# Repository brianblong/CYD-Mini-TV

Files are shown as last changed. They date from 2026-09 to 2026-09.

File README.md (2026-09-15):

# Mini TV

A DIY Wi-Fi picture frame built around an **ESP32-2432S028** display. The
project combines ESP32 firmware, a self-hosted photo portal, and a printable
retro television enclosure.

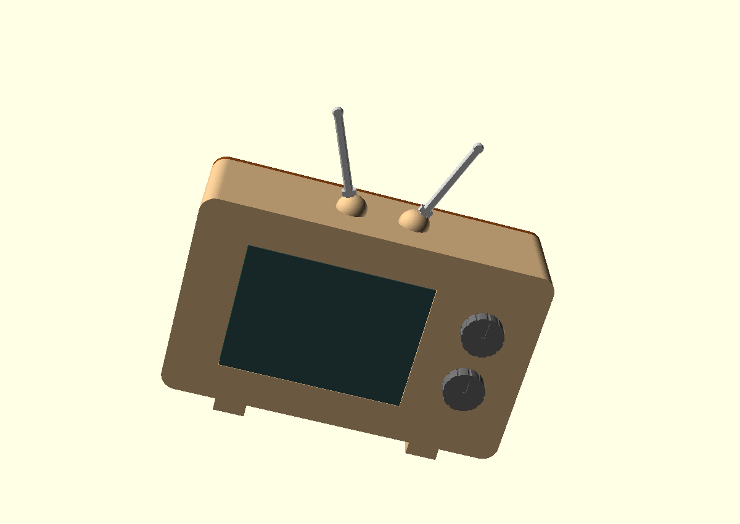
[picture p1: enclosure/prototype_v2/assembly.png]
Assembled retro Mini TV enclosure


The finished device can:

- display an ordered slideshow supplied by your own private server
- keep displaying a saved frame when the network is temporarily unavailable
- report device status to the photo portal
- receive signed firmware updates
- let you upload, arrange, preview, and remove pictures in a browser
- fit inside the included 3D-printable retro TV enclosure

This repository is a reusable blank template. It contains no personal photos,
Wi-Fi credentials, passwords, private signing keys, or deployment-specific
network details.

## How the pieces work together

```mermaid
flowchart LR
    A[Web browser] -->|HTTPS /admin| B[Reverse proxy]
    T[Mini TV] -->|HTTPS + device login| B
    B -->|Private container network| P[Flask photo portal]
    P --> D[(Photo catalogue)]
    P --> F[(Private firmware releases)]
    P -->|320 x 240 RGB565 frame| B
    B -->|Next slideshow frame| T
```

The browser is the control panel. The Mini TV is a separate authenticated
client. NGINX (or an equivalent reverse proxy) terminates HTTPS, verifies the
device login, and forwards trusted requests to the private Flask application.
The Flask application should not be exposed directly to the internet.

## Choose your starting point

| Goal | What you need | Start here |
| --- | --- | --- |
| See the portal without hardware | Python 3 and a browser | [Preview the portal](#1-preview-the-photo-portal) |
| Test the display | ESP32-2432S028, USB data cable, VS Code, PlatformIO | [Test the screen](#2-build-and-test-the-display) |
| Build the enclosure | 3D printer or printing service | [Print the enclosure](#3-print-the-enclosure) |
| Run the complete picture frame | All of the above plus a server, domain name, and HTTPS | [Deploy the complete system](#4-deploy-the-complete-system) |

## What you need

### Hardware

- one ESP32-2432S028 display board, often called a Cheap Yellow Display (CYD)
- a data-capable USB cable that fits your board revision
- a stable USB power supply for normal operation
- a microSD card only if you extend the project to use one; it is not required
  by the included network slideshow
- the printed enclosure parts and fasteners described below

ESP32-2432S028 boards are sold with different display controllers and connector
layouts. This repository includes ST7789 and ILI9341 build profiles, but you must
verify your own board. The manufacturer's
[reference downloads](https://www.guition.com/-download) are useful background;
physical measurements and a display test take priority.

### Software

- [Visual Studio Code](https://code.visualstudio.com/)
- the [PlatformIO IDE extension](https://platformio.org/install/ide?install=vscode)
- [Python 3](https://www.python.org/downloads/)
- Git, if you want to clone the repository
- Docker and a reverse proxy for a permanent server deployment
- OpenSCAD and a slicer such as Bambu Studio only if you want to modify or print
  the enclosure

## Project layout

```text
mini-tv/
|-- firmware/             ESP32 source, local settings template, and OTA tools
|-- homelab/portal/       Flask portal, browser interface, tests, and NGINX config
|-- enclosure/            OpenSCAD sources, STL files, renders, and print notes
|-- .gitignore            Prevents private/generated files from entering Git
|-- LICENSE               MIT license
`-- README.md             This guide
```

## 1. Preview the photo portal

Do this first if you want to explore the interface without configuring a server
or connecting the display. The preview listens only on your own computer and
creates temporary sample images.

1. Clone the repository and enter its directory:

   ```powershell
   git clone https://github.com/brianblong/CYD-Mini-TV.git
   cd CYD-Mini-TV
   ```

2. Create a private Python environment:

   ```powershell
   python -m venv .venv
   ```

3. Activate it in PowerShell:

   ```powershell
   .\.venv\Scripts\Activate.ps1
   ```

   If PowerShell blocks activation, use the environment's Python directly:

   ```powershell
   .\.venv\Scripts\python.exe -m pip install -r homelab\portal\requirements.txt
   .\.venv\Scripts\python.exe homelab\portal\preview.py
   ```

4. If activation succeeded, install the dependencies and start the preview:

   ```powershell
   python -m pip install -r homelab\portal\requirements.txt
   python homelab\portal\preview.py
   ```

5. Open <http://127.0.0.1:8765/admin/> in your browser.

6. When finished, return to the terminal and press **Ctrl+C** to stop it.

The preview is for inspecting the design. For persistent photos and an actual
Mini TV connection, continue to the deployment section.

## 2. Build and test the display

Start with the safe blank configuration. This verifies the display controller,
orientation, colors, USB connection, and build tools before credentials are added.

1. Install VS Code and the PlatformIO IDE extension.
2. In VS Code, choose **File > Open Folder** and open the repository's
   `firmware` folder—not the repository root.
3. Connect the ESP32 display with a data-capable USB cable. A charge-only cable
   can power the board but cannot upload firmware.
4. Wait for PlatformIO to finish installing the pinned ESP32 platform and
   libraries on its first run.
5. In the PlatformIO sidebar, open
   **Project Tasks > cyd_st7789_check > General > Build**.
6. A successful build ends with `SUCCESS`. This check uses the public blank
   settings and is safe to compile, but is not intended for normal network use.
7. To test the common ST7789 board, select
   **Project Tasks > cyd_st7789 > General > Upload**. With blank settings, the
   screen shows the neutral startup/color test instead of connecting to Wi-Fi.
8. If the image has the wrong colors, orientation, or no usable output, try the
   **cyd_ili9341** environment.
9. Open **Monitor** under the same environment to view diagnostic messages. The
   serial speed is **115200 baud**.
10. If PlatformIO cannot choose a port, find the board's COM port in Windows
    Device Manager and temporarily add these lines under `[env]` in
    `firmware/platformio.ini`:

    ```ini
    upload_port = COM3
    monitor_port = COM3
    ```

    Replace `COM3` with the port shown on your computer. Avoid committing a
    machine-specific port unless you intentionally want it in your fork.

For controller details, see the [firmware guide](firmware/README.md).

## 3. Print the enclosure

The recommended enclosure is **Prototype V3**, which has threads built into its
PCB supports and rear posts. It reuses the V2 exterior geometry and no longer
requires eight separate nuts.

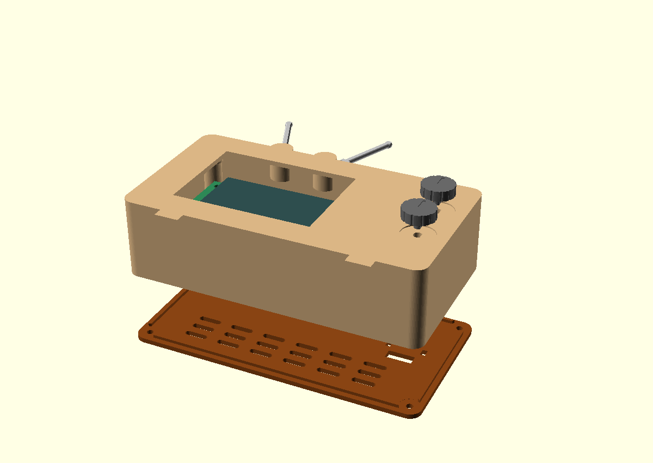
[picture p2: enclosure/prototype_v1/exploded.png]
Exploded enclosure showing the screen, housing, controls, and back


### Parts to print

From `enclosure/prototype_v3/`:

- `housing.stl` — main television body
- `back_cover.stl` — removable ventilated rear cover
- `knobs.stl` — decorative front controls
- `antennas.stl` — decorative top antennas

Before printing the full housing, also print:

- `fit_coupon.stl` — small threaded test section
- `test_spacers.stl` — simulates the PCB and back-cover thicknesses

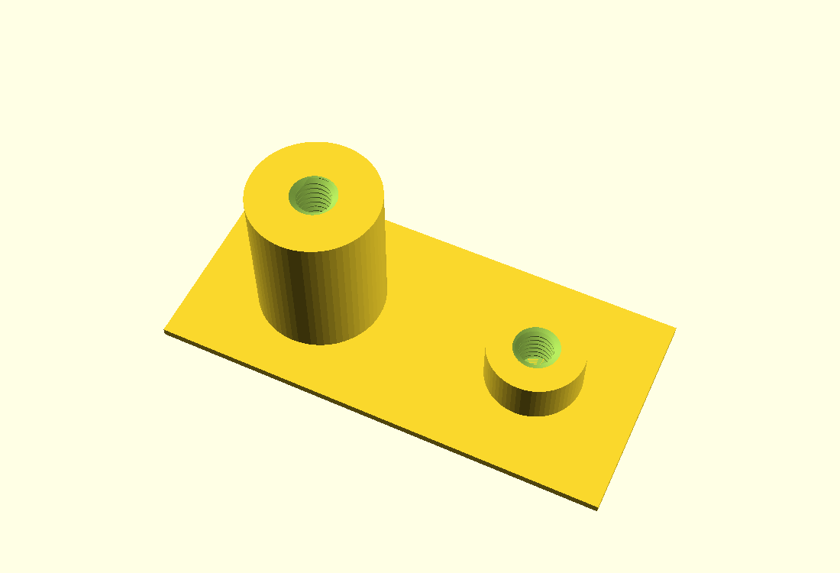
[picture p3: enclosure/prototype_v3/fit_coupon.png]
Thread and spacer fit test


### Suggested print sequence

1. Import `fit_coupon.stl` and `test_spacers.stl` into your slicer at **100%**
   scale. Do not mirror them.
2. Start with PLA, a **0.20 mm** layer height, four walls, 100% infill, and no
   supports for these small tests.
3. Inspect the sliced threads. If the 0.5 mm pitch is poorly formed or binds,
   retry the tests at **0.08 or 0.10 mm** layer height.
4. Test the short post with the 1 mm spacer and an M3 x 4 mm screw. Test the tall
   post with the 2.4 mm spacer and an M3 x 10 mm screw. Turn gently by hand and
   never force a binding screw.
5. After both tests pass, import `housing.stl` front-down with the cavity facing
   upward. A starting point is four walls, five top/bottom layers, and 15% infill.
6. Paint supports only beneath the lower outside curves of the antenna bases.
   Keep supports out of the threads and sockets.
7. Print the remaining back cover, knobs, and antennas at 100% scale.

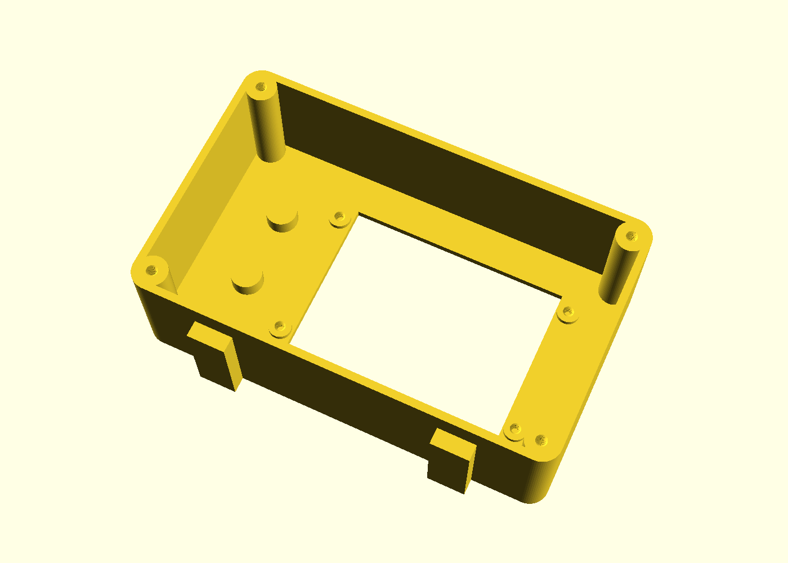
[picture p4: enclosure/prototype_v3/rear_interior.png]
Rear enclosure interior and mounting points


### Assembly

1. Disconnect power from the display.
2. Insert the PCB from the rear with USB-C pointing toward the knob side.
3. Confirm all four PCB corners rest on their support pads and the display glass
   sits flush with the front opening.
4. Attach the PCB using four M3 x 4 mm screws. Tighten only until snug; bending
   the PCB or loading the glass can damage it.
5. Route the USB cable through the rear opening.
6. Install the back cover using four M3 x 10 mm screws.
7. Fit the decorative knobs and antennas.

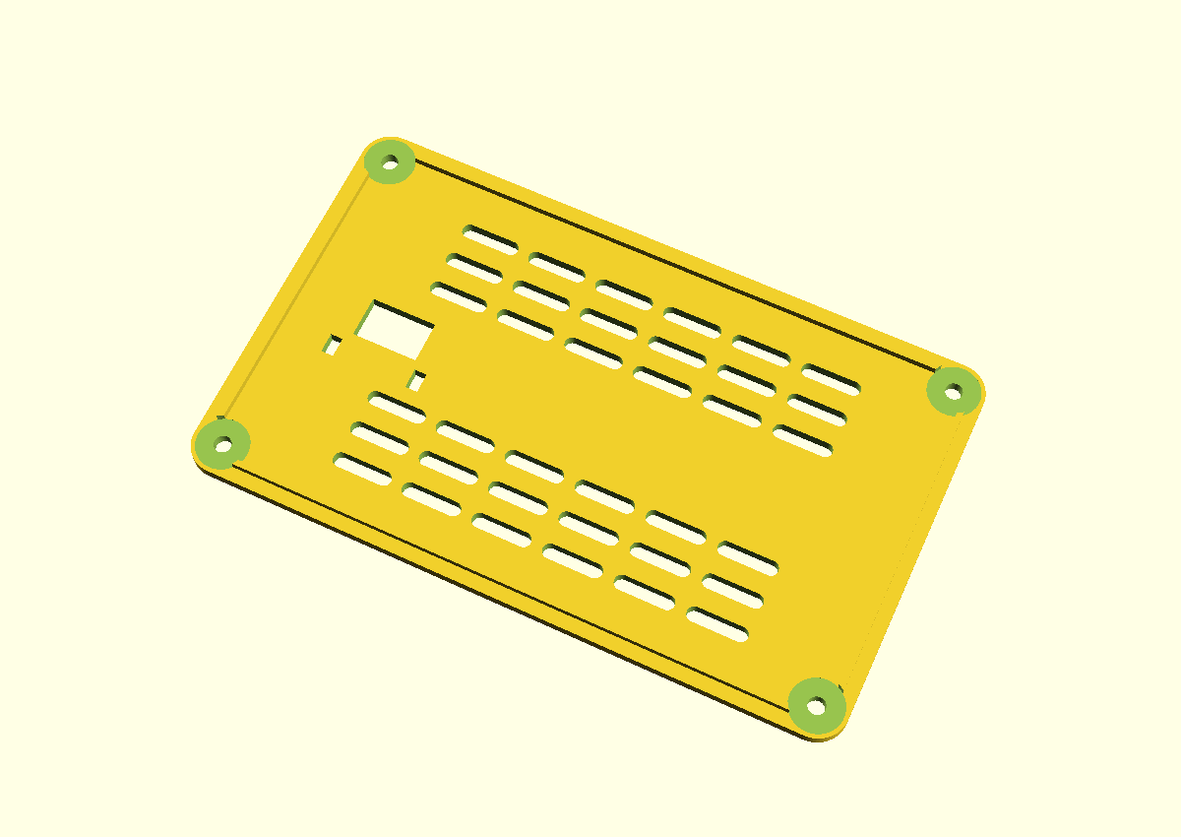
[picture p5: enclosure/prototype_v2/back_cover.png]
Back cover with ventilation and cable opening


Read the complete [Prototype V3 print and assembly notes](enclosure/prototype_v3/README.md)
before printing. Dimensions and threaded fits vary by printer, material, nozzle,
and board revision, so the small test print is intentional.

## 4. Deploy the complete system

This stage assumes you know how to administer a server or homelab. The included
configuration provides the application pieces, but does not automatically buy a
domain, configure your router, obtain TLS certificates, or back up your data.

### 4.1 Prepare private server storage

On the Linux server, create persistent photo and release directories:

```bash
sudo mkdir -p /opt/mini-tv/data/photos
sudo mkdir -p /opt/mini-tv/data/private/firmware/tv-local
sudo mkdir -p /opt/mini-tv/data/private/firmware/tv-remote
sudo chmod 700 /opt/mini-tv/data/private
```

Keep these directories outside the public Git checkout. Photos, generated
catalogue data, and firmware releases are personal deployment data.

### 4.2 Create the portal's private configuration

1. Copy `homelab/portal/portal.env.example` to a private location named
   `portal.env`.
2. Generate a Flask session key:

   ```powershell
   python -c "import secrets; print(secrets.token_hex(32))"
   ```

3. Generate the hash for the password you will use to sign into the website:

   ```powershell
   python -c "from werkzeug.security import generate_password_hash; print(generate_password_hash(input('Password: ')))"
   ```

4. Put the generated values into `PORTAL_SECRET_KEY` and
   `ADMIN_PASSWORD_HASH`. You may also change the generic site title, tagline,
   and display names.

Never put the completed `portal.env` in Git, a screenshot, an issue, or a shared
chat. The repository's `*.env` rule is a safety net, not a password vault.

### 4.3 Run the portal container

Build `homelab/portal/Dockerfile`, mount persistent photo storage at `/data`,
mount private releases at `/firmware` as read-only, and load the private
environment file. Keep container port 8000 on a private Docker network.

The provided `nginx-default.conf` expects the upstream container to be named
`portal`. Install it as the active server block for the reverse-proxy container,
not as a second conflicting block. Provide HTTPS at the public edge before
sending real credentials or photos.

### 4.4 Add device authentication

Create one NGINX Basic Auth identity per display, such as `tv-local` and
`tv-remote`. Give every device a unique generated password. The username used by
the firmware must exactly match the username in the reverse proxy.

Device traffic follows this path:

```mermaid
sequenceDiagram
    participant TV as Mini TV
    participant N as HTTPS reverse proxy
    participant P as Private Flask portal
    TV->>N: GET /device/next + Basic Auth
    N->>N: Verify username and password
    N->>P: Forward with trusted device identity
    P-->>N: Next prepared frame
    N-->>TV: 320 x 240 RGB565 data
    TV->>N: POST /device/heartbeat
    N->>P: Authenticated device status
```

The Flask device routes trust the identity header supplied by NGINX. Do not
publish port 8000 or allow clients to bypass the reverse proxy.

### 4.5 Configure the Mini TV privately

1. Copy the example file:

   ```powershell
   Copy-Item firmware\include\secrets.example.h firmware\include\secrets.h
   ```

2. Open `firmware/include/secrets.h` and enter:

   - the SSID and password for your 2.4 GHz Wi-Fi network
   - an optional second Wi-Fi network, or leave those two fields blank
   - your HTTPS portal hostname without a path
   - the device username and its matching Basic Auth password

3. Confirm Git is ignoring the completed file:

   ```powershell
   git check-ignore -v firmware/include/secrets.h
   ```

   Git should print the matching `.gitignore` rule. If it prints nothing, stop
   and fix the ignore rule before staging any files.

4. Build and upload the correct `cyd_st7789` or `cyd_ili9341` environment from
   PlatformIO.
5. Watch the 115200-baud serial monitor and verify Wi-Fi, HTTPS, authentication,
   frame download, and portal status reporting.
6. Upload a non-sensitive test picture through `/admin/`, place it in the
   playlist, and confirm it appears on the display.

### 4.6 Verify failure behavior

Before relying on the frame, test each condition separately:

- restart the display and confirm it reconnects
- temporarily stop the portal and confirm the saved frame remains visible
- restore the portal and confirm the slideshow resumes
- try an incorrect device password and confirm the request is rejected
- verify the portal is reachable only through HTTPS
- verify port 8000 is not publicly reachable

## 5. Optional signed firmware updates

USB remains the simplest recovery path. Configure over-the-air updates only
after the basic slideshow is reliable.

1. From the `firmware` directory, initialize a signing identity once:

   ```powershell
   python tools\release.py init
   ```

2. This creates the private signing key and installation-specific public-key
   header in ignored locations. Back up the private key in encrypted storage.
3. Increase the firmware version before every release.
4. Build using the intended device configuration.
5. Package the release using `tools/release.py`.
6. Copy the resulting private binary and manifest into the matching server
   release directory. Upload the binary first and publish the manifest last.
7. Test updates while the display is physically accessible by USB.

Firmware binaries built with real settings contain credentials. Never attach
them to a public GitHub release. See the detailed
[deployment template](firmware/DEPLOYMENT.md) and
[firmware validation guide](firmware/VALIDATION.md).

## Privacy and security checklist

Before every public commit, confirm that you have not staged:

- `firmware/include/secrets.h`
- a completed `.env` file
- Wi-Fi names or passwords
- real domains, internal hostnames, or IP addresses
- personal photographs or generated catalogue data
- Basic Auth password files
- OTA private keys or installation-specific public-key headers
- firmware binaries compiled with credentials

Useful checks:

```powershell
git status
git diff --cached
git check-ignore -v firmware/include/secrets.h
```

`.gitignore` prevents common accidents, but it cannot remove a secret that was
already committed. If that happens, rotate the exposed credential immediately;
deleting the visible line in a later commit does not erase it from Git history.

## Run the automated checks

From the repository root, after installing the portal requirements:

```powershell
python -m unittest discover -s homelab/portal -p "test_*.py"
node --check homelab/portal/static/portal.js
python -m unittest discover -s firmware/tools -p "test_*.py"
```

PlatformIO also provides the `cyd_st7789_check` environment for a safe compile
with blank example credentials.

## More documentation

- [Firmware setup](firmware/README.md)
- [Deployment template](firmware/DEPLOYMENT.md)
- [Device/server protocol](homelab/portal/DEVICE_PROTOCOL.md)
- [Photo portal](homelab/portal/README.md)
- [Enclosure overview](enclosure/README.md)
- [Prototype V3 enclosure](enclosure/prototype_v3/README.md)

## License

The source code and original project files are released under the
[MIT License](LICENSE). Third-party hardware, software, and linked reference
materials remain subject to their respective owners' terms.

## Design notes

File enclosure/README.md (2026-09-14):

# CYD enclosure

## Latest: V3 integrated-thread fit trial

Use [prototype_v3/README.md](prototype_v3/README.md) for the housing with threaded
PCB supports and rear posts, eliminating all eight nuts. Existing screw lengths
and the flush display position stay the same. Start with its threaded test
coupon and spacers before reprinting the housing. Reuse the V2 back with the
enlarged 13.4 x 8.4 mm cable opening, knobs and antennas. Printed thread fit is
not yet physically confirmed. The earlier nut-based V2 remains available below.

## Previous: V2

Use [prototype_v2/README.md](prototype_v2/README.md) for the revised housing and
back. Width is 132 mm with equal 12.9 mm gaps beside the unchanged knobs.
The antenna sockets now sit in hemisphere bases centered on the case top.
The back keeps its vent/cable/fastener design, resized horizontally to match.
The V1 knobs, antenna rods and small fit coupon can be reused unchanged.
V2 housing requires local supports beneath the domes when printed front-down.

## Full prototype V1

The fitted housing, removable back, separate knobs/antennas and a small socket
test are retained in [prototype_v1](prototype_v1/README.md). Those instructions
describe V1 only. The older files below are retained as reference and gauge history.

V1 uses the now-measured 4 mm glass projection, 1 mm PCB and 11 mm total depth.
Its glass is flush with the front; its right compartment allows the 30 mm USB-C
plug projection. The closed rear hole is 13.4 x 5.4 mm for the measured 13 x 5 plug.

Latest PCB dimensions: 86 x 50.5 mm. Latest hole center spacing: 78.5 x 42 mm.
These supersede earlier measurements. All model dimensions are in millimeters.

## First alignment test

Import `cyd_alignment_test.stl` into Bambu Studio, select your P1S, keep scale at
100%, and check dimensions are 86 x 58.5 x 1.6 mm. The extra 8 mm is the pair
of outside bridges; the PCB reference area remains 86 x 50.5 mm. Keep the broad flat face on the
plate. Use your normal PLA profile with 0.20 mm layers and no supports. Slice,
inspect the preview, and print using your normal printer workflow.

After cooling, disconnect the board from power. Compare the printed outline and
four holes with the PCB without pressing against glass or rear components.
Do not force screws through or tighten the board onto this gauge.
Report which holes or edges fail to align together.

The origin is lower-left viewed from the display side. Keep that orientation:
flipping the gauge swaps the unequal margins. Provisional centers are (4,4),
(82.5,4), (4,46), (82.5,46). Left/bottom margins are 4; right is 3.5; top is 4.5.
The earlier claim of 4 mm at every edge cannot hold with the latest dimensions.
The physical test will check the provisional offsets.

The revised gauge has 8 mm side rails and 3.4 mm holes, 0.2 mm above nominal
board-hole diameter. Its 4 mm top and bottom connecting bridges sit outside the
PCB outline, leaving a 70 x 50.5 mm full-height opening so they do not cover the
flush display.
Printing tolerances make this an approximate layout test, not a precision gauge.
This verifies the outer display-module clearance, not the smaller illuminated area.

## OpenSCAD files

- `cyd_dimensions.scad`: shared adjustable board measurements and verification flags.
- `cyd_alignment_test.scad`: printable outline/hole gauge; open and press F5.
- `cyd_reference.scad`: board reference; 0.4 mm sheet thickness is illustrative only.
- `cyd_nominal_footprint.svg`: latest outline/provisional holes for paper comparison,
  not a verified drilling template. Print actual size and measure the result.
- `retro_tv_concept.scad`: styling only, not a fitted printable enclosure.

`include` reads dimensions, `difference` subtracts the middle and holes, and
`linear_extrude` gives the gauge thickness. After editing, F6 renders the model;
File > Export > Export as STL updates the printable file.

The reference's blue rectangle is the nominal 57.6 x 43.2 active display area,
shown separately because its position is unknown. PCB thickness, frame geometry,
assembly depth, USB cutouts, microSD and button access remain undefined.
`require_verified=true` rejects finalization while required measurements are missing.
See `measurement_notes.md` for conflicting earlier readings.

## Final case intentions

Retro TV, decorative knobs, mini top antennas, no lettering or front screw heads.
Board screws will be accessed from the rear into internal standoffs, supporting
PCB rather than glass. Screw lengths and standoff heights require depth and
component-clearance measurements. A separate back cover will have upper/lower
vents, with a rear cable notch and strain relief for an internal USB-C cable
running to an external USB power adapter. These features are not in the test gauge.

The manufacturer's [ESP32-2432S028 specification](https://www.guition.com/-download)
illustrates a micro-USB-only board, so its 86 x 50 outline, 78 x 42 spacing and
3.2 mm hole diameter do not verify every revision. Physical measurements override
nominal values; verify the hole diameter and connector layout for your own board.

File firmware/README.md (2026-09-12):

# Mini TV firmware

This PlatformIO project targets ESP32-2432S028 displays. It connects to a private
photo portal, downloads display-ready frames, keeps an offline snapshot, reports
device status, and supports application-level signed OTA updates.

The repository contains blank example settings only. A fresh build starts with a
neutral color test until a server frame is available.

## Requirements

- VS Code with the PlatformIO IDE extension
- an ESP32-2432S028-compatible display
- a data-capable USB cable
- access to a configured Mini TV photo portal

## Private configuration

Copy `include/secrets.example.h` to `include/secrets.h` and enter your own values.
The completed file is ignored by Git.

```cpp
constexpr char WIFI_SSID[] = "";
constexpr char WIFI_PASSWORD[] = "";
constexpr char REMOTE_WIFI_SSID[] = "";
constexpr char REMOTE_WIFI_PASSWORD[] = "";
constexpr char TV_SERVER_HOST[] = "photos.example.com";
constexpr char TV_SERVER_USER[] = "tv-remote";
constexpr char TV_SERVER_PASSWORD[] = "";
```

The optional second Wi-Fi network is tried first and the primary network is used
as a fallback. Leave the second network blank if it is unnecessary.

Never commit `secrets.h`. Credentials are compiled into normal firmware binaries,
so do not publish or share release binaries built with real settings.

## Build and upload

Open the `firmware` directory as the VS Code folder. In PlatformIO, use:

1. **Project Tasks → cyd_st7789 → General → Build**
2. **Project Tasks → cyd_st7789 → General → Upload**
3. **Project Tasks → cyd_st7789 → General → Monitor**

The default monitor speed is 115200 baud. If automatic serial-port detection is
ambiguous, set `upload_port` and `monitor_port` in `platformio.ini` to the port
shown by your operating system.

The `cyd_st7789_check` environment compiles with blank example settings for safe
validation. Do not flash that environment to a device you expect to connect.

## Display profiles

The default profile is the ST7789 revision. An alternate `cyd_ili9341` environment
is included because ESP32-2432S028 boards exist with different display controllers.
Board labels alone may not identify the panel revision; validate colors, rotation,
and pin behavior on your hardware.

## OTA signing

Run `python tools/release.py init` once to create `keys/ota-private.pem` and
`include/ota_public_key.h`. Both installation-specific files are ignored by Git;
the repository ships a compile-only placeholder instead. Keep the private key out
of Git and back it up in encrypted storage. Losing it requires a USB installation
of firmware containing a new signing identity.

See [DEPLOYMENT.md](DEPLOYMENT.md) for the generic server and device workflow.

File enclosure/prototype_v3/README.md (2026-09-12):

# Prototype V3: threads built into the housing

Physical testing confirmed the screws tighten successfully. For the Allen-key
recess slipping, the optional [slotted-head screws](slotted_screws/README.md)
provide a wider flat-head drive and six outer flats with unchanged threads.
No housing change is needed for those screws.

All eight nut pockets are removed. The PCB supports and rear corner posts now
contain blind, right-handed threaded holes using the existing printed screws'
0.5 mm pitch and the printed nuts' 0.30 mm diametral trial clearance. No nuts
are required. This is an experimental fit, not a certified M3 thread.

Keep the existing screws: four M3 x 4 mm for the PCB and four M3 x 10 mm for the
back. The unchanged printed screw STLs remain in
`../prototype_v2/experimental_screws/`. Do not use 10 mm screws on the PCB.

The PCB screw passes through the 1 mm board and penetrates the support by 3 mm.
Its hole is 3.4 mm deep, with a 0.4 mm tip gap and 0.6 mm closed floor protecting
the front face. The rear screw passes through the 2.4 mm back and penetrates
7.6 mm into an 8.2 mm hole. The screw's tapered tip and hole entrance chamfer
reduce full thread engagement below these penetration lengths.

The PCB contact plane remains 4 mm behind the case front, keeping the measured
glass flush. Body dimensions, hole locations, screen opening, knobs, antennas,
vents and enlarged 13.4 x 8.4 mm cable opening are unchanged. Reuse the V2 back
cover, knobs and antennas. Their V3 STLs are identical copies. V2 remains intact.

## Print the small test first

1. Import `fit_coupon.stl` and `test_spacers.stl` into Bambu Studio as separate
   objects. Keep 100% scale and supplied orientations. Do not mirror them.
2. Use your P1S and actual nozzle profile. Try your requested 0.20 mm layer height,
   4 walls and 100% infill on these small test objects, with supports off.
3. The 0.5 mm thread pitch spans only 2.5 layers at 0.20 mm. Inspect the sliced
   threads. If they do not form or bind, try 0.08 or 0.10 mm layers with the
   appropriate printer profile before printing the full housing. Printed fit
   and strength have not yet been confirmed.
4. Put the smaller, 1 mm thick spacer over the SHORT post, then use an existing
   4 mm PCB screw. This simulates the PCB without risking the real electronics.
5. Put the larger, 2.4 mm thick spacer over the TALL post, then use an existing
   10 mm back-cover screw. This simulates the cover. Turn clockwise gently.
6. Each screw should start by hand and snug the spacer without spinning freely
   or stopping while the spacer is loose. Do not force a binding screw. The
   two spacers are for this test only, not extra washers for final assembly.

## Housing and assembly

After the test succeeds, print `housing.stl` front down, cavity up at 100% scale.
Use the successful thread settings from the coupon. A starting point for the
housing is 4 walls, 5 top/bottom layers and 15% infill. As with V2, manually paint
local supports under the lower external curves of the antenna half-spheres.
Keep supports out of the threads and other sockets. Inspect the sliced supports.

With power unplugged, insert the PCB from the rear, USB-C pointing toward the
knob side. Seat all four corners on the support pads; check the glass is flush.
Fit the 4 mm screws through the PCB into the integrated threads. Snug gently by
hand; do not bend the PCB. Route the USB cable through the existing enlarged
back opening, attach the back, and use the 10 mm screws in its corner posts.
Use no nuts or test spacers in the enclosure.

Integrated threads provide more continuous plastic for the screw to engage,
but do not establish that insufficient engagement caused the previous failure.
Poor thread resolution, fit clearance or stripping can still prevent clamping.
Repeated assembly can wear printed threads; physical retention needs testing.

## Source and validation

`mini_tv.scad` is the editable source. It imports the unchanged V2 screw geometry
and shared `../cyd_dimensions.scad`. `build.ps1` exports and checks the models.
`finish_meshes.py` cleans microscopic export slivers using the existing helper.
`verify_meshes.py` checks mesh closure, winding, volume, bodies and bounds.
`verify_threads.py` checks the actual exported holes for pitch, handedness and
blind depth. The cutter is pre-mirrored because the case print transform also
mirrors X; omitting that compensation would create left-handed holes.

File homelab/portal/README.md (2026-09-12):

# Mini TV photo portal

This Flask application stores an ordered photo catalogue, prepares 320 × 240
RGB565 frames for Mini TV devices, accepts authenticated device check-ins, and
serves signed firmware releases through an NGINX reverse proxy.

Personal photos and credentials belong in deployment storage, not in this source
directory or its Git history.

## Configuration

Copy `portal.env.example` to a private deployment location named `portal.env`.
Fill in the two secret values and optionally change the branding fields. The
`.gitignore` rule for `*.env` prevents the resulting file from being committed.

Generate values rather than inventing short secrets:

```powershell
# Random Flask session key
python -c "import secrets; print(secrets.token_hex(32))"

# Password hash for the website login
python -c "from werkzeug.security import generate_password_hash; print(generate_password_hash(input('Password: ')))"
```

Do not paste the resulting values into source code, screenshots, issues, or
commits.

## Run locally

Create a Python virtual environment, install `requirements.txt`, set the required
environment variables from your private configuration, and run Flask or Gunicorn.
The included `preview.py` creates temporary sample images and serves a loopback-only
design preview at `http://127.0.0.1:8765/admin/`.

## Production outline

1. Build the included Dockerfile.
2. Mount persistent photo storage at `/data`.
3. Mount private firmware releases at `/firmware` as read-only.
4. Load the private environment file into the container.
5. Put the container behind the provided NGINX configuration and HTTPS.
6. Create Basic Auth users matching the configured firmware device identities.
7. Keep the Flask container private to the container network; do not publish port
   8000 directly.

The NGINX configuration overwrites `X-Mini-TV-User` with the authenticated user
before proxying a device request. Do not expose the Flask device routes directly,
because they trust that verified identity header.

## Tests

From the repository root, with the dependencies installed:

```powershell
python -m unittest discover -s homelab/portal -p "test_*.py"
node --check homelab/portal/static/portal.js
```

Tests cover authentication, CSRF protection, uploads, catalogue persistence,
ordering, deletion, device status, and frame delivery.

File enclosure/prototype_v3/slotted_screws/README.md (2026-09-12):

# Slotted hex-head screws

Physical testing found that the V3 screws tighten successfully, but the small Allen-key
recess strips. These screws change only the head: a straight rectangular slot
replaces the 2.1 mm hex socket, and six exterior flats replace the round rim.
The slot is 4.2 mm long, 1.0 mm wide and 1.2 mm deep, leaving 1.2 mm of plastic
between its floor and the underside of the head. Maximum head diameter stays
5.5 mm and head height stays 2.4 mm. The hex measures approximately 4.76 mm
across flats; it is not a standard 5 mm wrench size.

The successful shaft/thread module is imported unchanged from the original
source: 2.88 mm major diameter, 0.5 mm right-hand pitch, same tapered tip,
4 mm PCB length and 10 mm back-cover length. Existing housing holes need no
changes, and no housing reprint is required.

## Print and test

1. Print `test_screw.stl` first, using the settings that worked for your threads.
   Keep 100% scale, head flat on the bed, shaft upward, and supports off.
   Use 100% infill for these small screws.
2. After removal from the bed, clear any brim/first-layer residue from the slot.
   The slot is on the bottom face in the supplied print orientation.
3. Use a small FLAT-HEAD screwdriver, not the Allen key. Choose a blade that
   fits fully into the 4.2 x 1.0 mm opening with little sideways play; around
   3.5–4 mm blade width with thickness below 1 mm is a starting point.
4. Test gently in the existing threaded coupon with its thick spacer and the
   10 mm test screw. Seat the blade fully and keep it straight. Stop when snug.
   If access permits, the outside flats offer another grip, but do not squeeze
   or twist hard with pliers: the printed screw can still break.
5. If the grip works, print `pcb_screws_m3x4.stl` (four screws) and
   `back_screws_m3x10.stl` (four screws). Never use 10 mm screws on the PCB.

These remain experimental printed hardware. A larger slot spreads contact over
a wider area but does not guarantee resistance to stripping or over-tightening.
The revised head's tool fit and strength still need physical testing.

`screws.scad` is the editable source; `build.ps1` exports all three files.

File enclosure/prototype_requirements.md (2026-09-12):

# First full prototype

## User requirements

- Retro TV cabinet with no text or lettering.
- Display face flush with the exterior front surface, not recessed behind a lip.
- Fit-tested PCB outline: 86 x 50.5 mm.
- Fit-tested mounting centers: (4,4), (82.5,4), (4,46), (82.5,46).
- Revised gauge's 70 x 50.5 opening fits. This confirms aperture fit, not a
  precision measurement of the glass, its height, or its edge clearances.
- Concealed board fasteners accessible from the rear; support PCB, not glass.
- Separate removable rear cover, upper/lower ventilation, USB-C cable exit.
- Cable plugs into the PCB inside the cabinet and runs to an external USB adapter.
- P1S without AMS: separate printable housing, rear cover, knobs and antennas.
- Two black decorative knobs with locating pegs and matching housing sockets.
- Two gray antennas with pegs fitting sockets in small rounded top bases.
- Include assembly clearances in peg/socket fits; verify fit on a small coupon.

## Measurements supplied for V1

- Front glass to front PCB surface: 4 mm.
- PCB thickness: 1 mm.
- Front glass to furthest rear component: 11 mm.
- USB-C exits right from the front view; cable/plug projection is 30 mm.
- User specifies a closed rear opening for a 13 x 5 mm connector to pass through
  first. V1 adds 0.2 mm on each side. The earlier seam-notch option is superseded.

V1 source and separate STLs are in prototype_v1/. Support height is 4 mm; the
body is 150 x 80 x 40 mm to accommodate the board, plug corridor and knob sockets.
Fasteners use side-loaded M3 nuts, M3 x 4 board screws, and M3 x 10 cover screws.
Actual fastener clearances, print fits, cable bend and temperature need testing.

## V2 styling revision, 2026-09-06

The user requested less space on the knob side, equal screen-to-knob and
knob-to-right-edge gaps, and half-sphere antenna bases centered on the top.
V2 is 132 mm wide with 12.9 mm equal gaps and two radius-6 mm domes centered at
X=54/78 and depth=20. Knob/antenna parts are unchanged. The back retains its
design with a narrower horizontal layout. Confirmed USB-C center is 24 mm above
PCB bottom; an internal lower-knob support relief clears that plug envelope.
V2 is saved separately in prototype_v2; V1 remains available.

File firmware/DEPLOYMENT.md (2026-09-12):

# Mini TV deployment template

This guide deliberately uses placeholders. Replace them locally; do not commit
real hostnames, addresses, usernames, passwords, photographs, or private keys.

## 1. Prepare private server configuration

Copy `homelab/portal/portal.env.example` to a private server configuration named
`portal.env`. Generate the required secrets and choose optional display names.
Keep this file outside the application source directory when practical.

Create persistent server directories for photos and private firmware releases:

```bash
mkdir -p /opt/mini-tv/data/photos
mkdir -p /opt/mini-tv/data/private/firmware/tv-local
mkdir -p /opt/mini-tv/data/private/firmware/tv-remote
chmod 700 /opt/mini-tv/data/private
```

Configure your container deployment to:

- mount the photo directory at `/data`
- mount the firmware directory at `/firmware` as read-only
- load the private `portal.env`
- expose the portal only to the private container network
- route browser and device traffic through NGINX with HTTPS

## 2. Configure device authentication

Create separate NGINX Basic Auth users for `tv-local` and `tv-remote`, or update
the generic identifiers consistently in the firmware, portal, tests, and release
tool. Use unique generated passwords for each device.

The device endpoints must not bypass NGINX. The Flask application trusts the
identity header that the included NGINX configuration replaces after successful
authentication.

## 3. Configure firmware locally

Copy `firmware/include/secrets.example.h` to
`firmware/include/secrets.h`. Enter the Wi-Fi networks, HTTPS hostname, device
username, and matching device password. Confirm that Git ignores this file before
building.

## 4. Install over USB

Build and upload the correct display environment through PlatformIO. Keep physical
access to the device during the first installation. Verify:

- correct orientation and colors
- successful connection to each configured 2.4 GHz network
- valid HTTPS connection to the portal
- changing slideshow frames
- offline snapshot behavior after disconnecting the network
- status check-ins on the portal

## 5. Prepare signed updates

Run `python tools/release.py init` once to generate an ECDSA P-256 signing identity.
The resulting private key and installation-specific public-key header are ignored
by Git. Back up the private key securely.

Increase the firmware version before each release, build with the intended device
identity, and package it with `tools/release.py`. The resulting firmware binary
contains credentials and must stay in private deployment storage.

Upload the binary before its manifest, restrict both files to the deployment
account, and publish the manifest atomically. Test failed downloads and interrupted
updates while USB recovery remains available.

## 6. Back up the personal installation

Back up these private components separately from the public repository:

- `portal.env` and the Basic Auth password file
- the photo catalogue and image data
- each device's ignored `secrets.h`
- the OTA private signing key
- private firmware release binaries

Use encrypted storage with at least one additional copy. A GitHub repository,
including a private repository, is not a substitute for a secrets vault or a photo
backup.

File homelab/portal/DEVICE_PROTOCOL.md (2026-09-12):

# Device protocol v1

HTTPS only through NGINX Basic Auth. The portal's TCP port must stay private.
NGINX replaces `X-Mini-TV-User` with the authenticated account, clears upstream
Authorization, and the app accepts only `tv-local` or `tv-remote` with
`DEVICE_HEARTBEATS_ENABLED=true`.

- `POST /device/heartbeat`: updates server-side last-seen time; intended every 30 s.
- `GET /device/next?after=<32 lowercase hex id>`: returns the next catalogue picture,
  wrapping to the first. Unknown/deleted/absent cursor starts at the first picture.
  HTTP 204 means empty catalogue or the cursor already names the sole picture.
  HTTP 200 is exactly 153600 bytes of row-major, big-endian RGB565, 320 by 240.
  `X-Photo-ID` supplies the cursor, `X-Frame-SHA256` supplies the lowercase SHA-256
  digest. Clients validate the complete buffer before displaying it. The response
  is generated from stored PNGs, so no public-storage migration is needed.
- `GET /device/firmware/manifest.txt`: reads only the authenticated device's folder
  below FIRMWARE_DIR (default `/firmware`). Missing release returns 404 normally.
- `GET /device/firmware/<64 lowercase hex SHA256>.bin`: same per-device restriction.
  This mount belongs outside the NGINX public directory; binaries contain credentials.

Signed manifest is ASCII with LF line endings, including a final LF:

```text
MINITV1
tv-remote
cyd-st7789-4m-v1
10001
<decimal image length>
<lowercase SHA256 hex>
<DER ECDSA signature as lowercase hex>
```

The signature uses P-256 / SHA-256 over the first six lines, including their LFs.
The seventh line is excluded. The authenticated device, hardware/layout identifier,
increasing release number, size and digest are therefore bound by the signature.
The image itself is verified against that digest before activating its OTA slot.
HTTP redirects are disabled. Digest-named images are immutable; publish manifest
last via atomic rename. Signing keys never belong on the server.

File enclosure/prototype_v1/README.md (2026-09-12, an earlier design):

# Retro mini-TV: first full prototype

All dimensions are millimeters. The body is 150 wide x 80 high x 40 deep;
feet and antenna bases extend beyond that body. The back adds 2.4 mm of depth.
The side beside the knobs reserves a 30 mm cable-plug corridor beyond the PCB.
Physical fit, cable bend, fastener access and temperature still need testing.

## Files to print

| STL | Contents | Color / orientation |
| --- | --- | --- |
| `housing.stl` | Main shell, internal supports, feet, rounded antenna bases | Your body color; front face down, cavity up |
| `back_cover.stl` | Removable back, vents, cable hole, tie slots | Body color; flat exterior down, locating lip up |
| `knobs.stl` | Two matching decorative knobs | Black; faces down, pegs up |
| `antennas.stl` | Two matching antenna rods with insertion pegs | Gray; already lying on their flat undersides |
| `fit_coupon.stl` | Small connector, peg/socket and M3-nut fit test | Same filament/profile as housing; keep supplied orientation |

The knob and antenna STLs each contain two disconnected printable parts, by
design. Import each file separately; no AMS or filament change within a print
is needed. `mini_tv.scad` is the editable source, not a file to slice.

## Print the small parts first

Use your P1S and installed nozzle profile. A starting point for a 0.4 mm nozzle
is 0.20 mm layers, 3 walls, 5 top/bottom layers and 15% infill, using your normal
PLA profile. Keep 100% scale and the supplied orientations. There are short
bridges over nut pockets and an angled roof in each antenna socket. The design
avoids support-filled sockets; inspect those layers in the slicer preview.
Start without supports. A brim can help keep the narrow antenna rods attached.

1. Import `fit_coupon.stl`, `knobs.stl`, and `antennas.stl` on separate plates or
   print runs for the desired colors. Slice, inspect, and print.
2. On the coupon, test the D-shaped knob socket from its top and the antenna
   socket from its side. Both are slip fits; do not force them.
3. Slide a standard M3 hex nut into the side slot of the low, 4 mm tall section.
   Its retaining roof is the same thickness as the PCB supports in the case.
4. Feed the actual USB-C plug through the rectangular opening in the thin tab.
   It measures 13.4 x 5.4, allowing 0.2 per side around the supplied 13 x 5 plug.
5. If these fits work, print the housing and back cover. If a fit needs changing,
   change the source clearance and regenerate; do not scale the complete case.

## Flush screen and hidden board screws

The measured front glass is 4 mm above the front of the PCB. The support pads
place that PCB face 4 mm behind the case's exterior front, so the glass and case
front are at the same plane. PCB back is 5 mm behind the front; the furthest
rear component is 11 mm behind it. No front lip overlaps or clamps the glass.
The whole tested display-face opening is exposed, including its inactive border.
The preview's dark rectangle represents that whole face, not the active pixels.

The opening is 70.4 x 50.9: the accepted 70 x 50.5 opening plus 0.2 clearance per
side. Board mounting uses the accepted four-hole pattern. The glass stays off
the plastic; screw force is taken by the four PCB supports.

Use the following hardware (not included in the STLs):

- Four M3 x 4 mm pan/button-head machine screws for the PCB, no extra washers
  assumed in this length. Avoid substituting a longer screw.
- Four M3 x 10 mm pan/button-head machine screws for the rear cover.
- Eight regular M3 hex nuts, nominal 5.5 across flats x 2.4 thick. No locknuts
  or heat-set inserts: the pockets are 5.8 across flats x 2.6 high.
- One small cable tie for the pair of strain-relief slots on the back.

The standard M3 nut height is documented in the manufacturer
[Accu M3 DIN 934 datasheet](https://www.accu.co.uk/api/product-datasheet?id=268686).
Check the particular nuts you buy against the pocket dimensions and coupon.
The earlier discussion of M3 x 6 screws and heat-set inserts does not apply to V1.

Nuts enter horizontally through side-loading pockets and are trapped beneath
plastic roofs. This is essential: simply dropping nuts into rear-open recesses
would not secure the PCB to the housing. The shallow PCB nut roofs are 0.8 mm
thick; snug the board screws gently by hand. The 4 mm PCB screw length accounts
for the 1 mm PCB, 0.8 mm roof and approximately 2.2 mm of nut engagement.

## Assemble

1. With the board unplugged, slide four nuts into the shallow board-support
   pockets. Use tweezers or a small blunt tool if helpful. Slide four more nuts
   into the side pockets near the ends of the tall corner posts.
2. Insert the CYD from the rear. From the FRONT, USB-C must face right, toward
   the knobs. From the open BACK, that same socket appears on the left.
3. Rest the PCB on all four support pads. Check that its front glass is level
   with the case and that components and screw heads have clearance. If it
   rocks or the glass is pushed against an edge, stop and adjust the model.
4. Install the four M3 x 4 board screws from the rear. They pass through the PCB
   into the captured nuts. Tighten only enough to hold the board on its pads.
5. Feed the USB-C connector from outside the rear cover through its rectangular
   hole, then plug it into the board. Arrange the cable's natural curve in the
   right-hand compartment and loosely secure it with the cable tie. Do not use
   the cover to force a stiff plug/cable into a tighter bend.
6. Seat the back cover's locating lip, then install four M3 x 10 screws. Removing
   the back later does not release the PCB. BOOT/RESET and microSD are accessed
   with the cover removed in this prototype.
7. Align each knob's D-shaped peg with its socket and insert gently. Insert each
   antenna peg into its rounded top base until its wider collar reaches the base.
   The rods point outward. These are decorative, not electrically connected.

The peg/socket diameter clearance is 0.35 mm. It is a slip-fit prototype, not a
guaranteed friction lock. If loose after testing, a tiny amount of suitable glue
on the pegs can retain them; apply with electronics removed and let it cure.
Try all fits before permanent attachment.

Use an external USB power adapter. Ventilation is provided by 36 rear slots,
split between upper and lower banks. Temperature performance is unmeasured:
check it during the first enclosed run and keep both vent banks unobstructed.

## Editable source and checks

Open `mini_tv.scad` in OpenSCAD and press F5 to see the colored assembly. Change
`part` to `exploded` for separation, or to `housing`, `back`, `knobs`, `antennas`,
or `fit_coupon` for individual parts. For a part, F6 then File > Export > Export
as STL creates its file. The assembly includes an illustrative board; do not
export the assembly as a printable object.

Part exports are oriented for printing. The construction drawing uses X right,
Y up from the screen side, with depth toward the rear. Export transforms account
for looking at the front from the opposite side of the build plate. Do not mirror
parts in Bambu Studio; that would reverse the fitted board-hole layout.

`build.ps1` regenerates the five STLs using the installed OpenSCAD CLI.
`verify_meshes.py` checks closed edges, winding, connected-part counts, print-bed
placement, positive volume and bounding dimensions. `part="collision_check"`
checks modeled housing overlaps against the board, cover, knobs and antennas,
with 0.01 mm separation at intended seating contacts to avoid coplanar artifacts.
It does not model actual rear component shapes, cable flexibility or hardware
head clearance; those remain physical prototype checks.

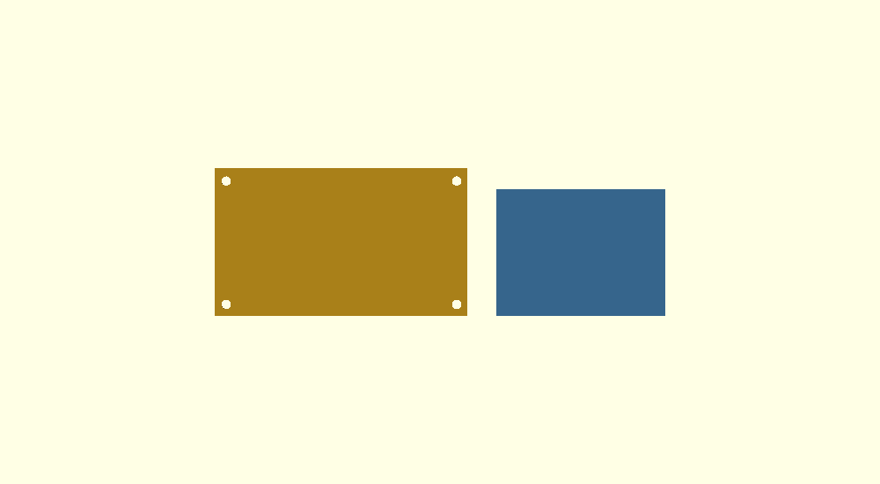
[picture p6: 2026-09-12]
enclosure/cyd_reference_preview.png

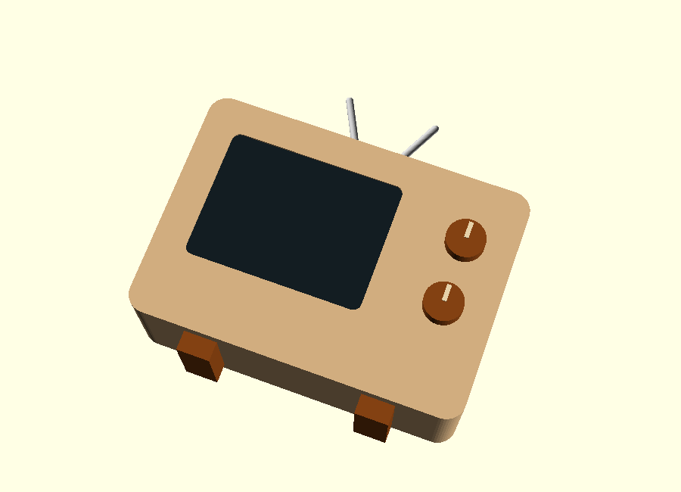
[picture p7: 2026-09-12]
enclosure/retro_tv_preview.png

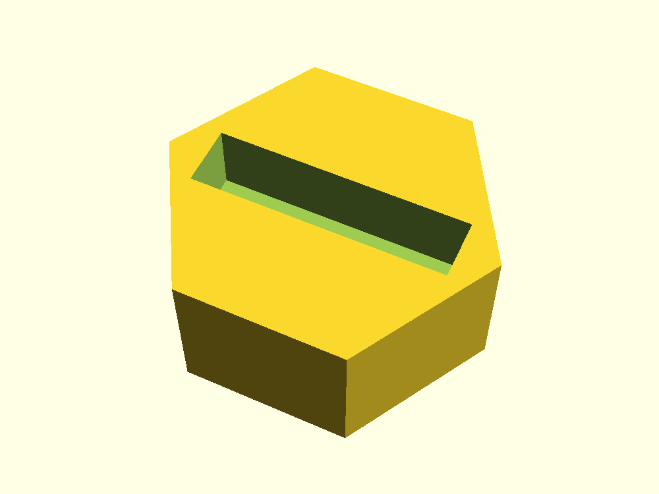
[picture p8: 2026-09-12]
enclosure/prototype_v3/slotted_screws/head_preview.png

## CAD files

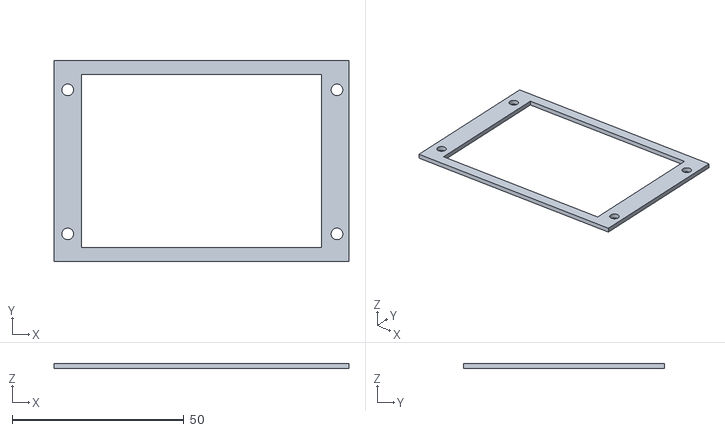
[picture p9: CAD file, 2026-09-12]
enclosure/cyd_screen_fit_test.stl
86.0 x 58.5 x 1.60

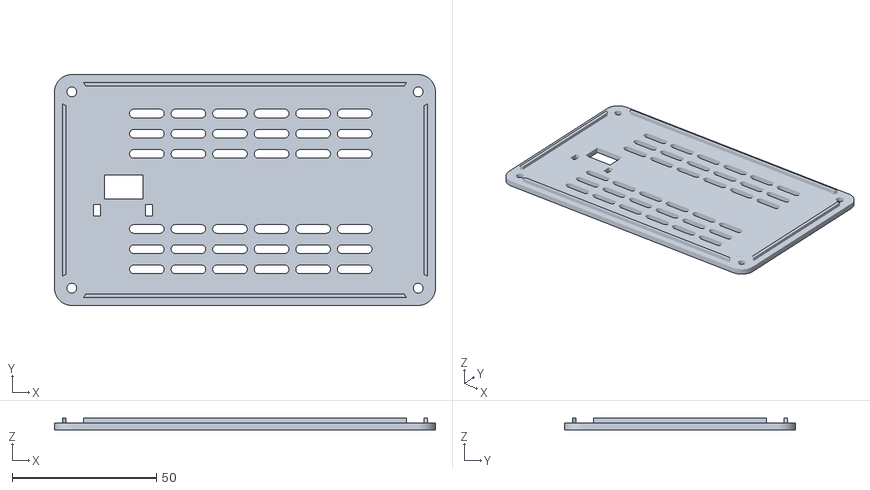
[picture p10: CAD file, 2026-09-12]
enclosure/prototype_v3/back_cover.stl
132.0 x 80.0 x 4.00

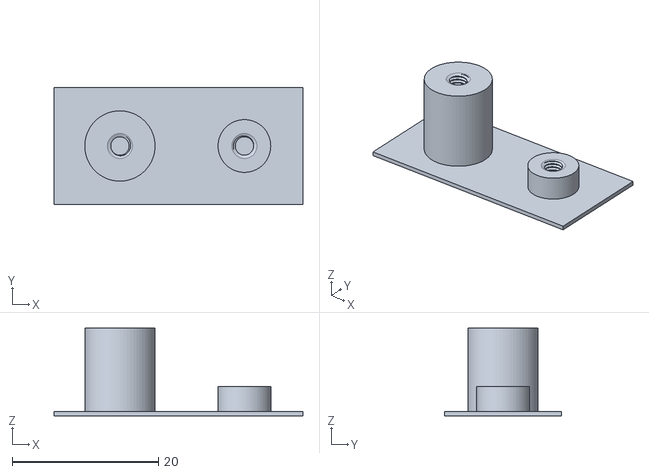
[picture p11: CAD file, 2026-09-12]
enclosure/prototype_v3/fit_coupon.stl
34.0 x 16.0 x 12.0

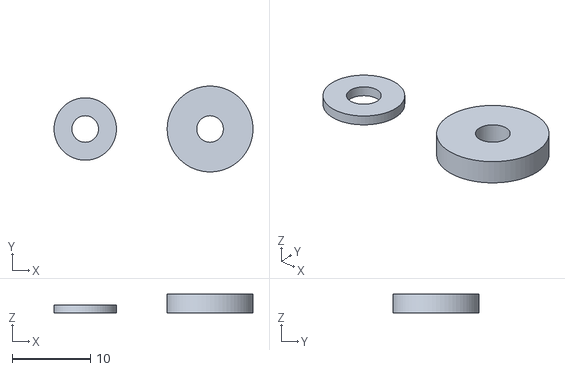
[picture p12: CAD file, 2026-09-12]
enclosure/prototype_v3/test_spacers.stl
25.5 x 11.0 x 2.40

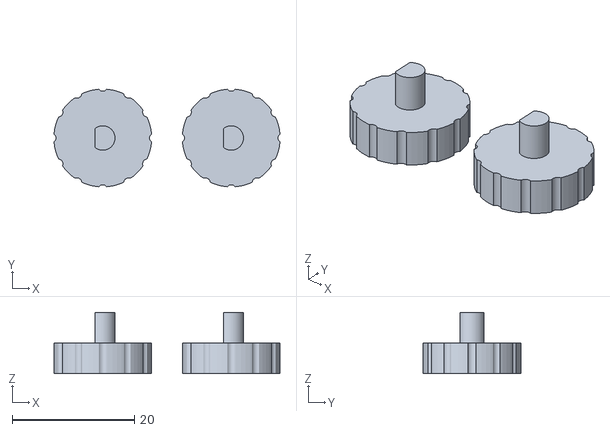
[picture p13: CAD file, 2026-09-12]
enclosure/prototype_v3/knobs.stl
36.9 x 15.9 x 10.0

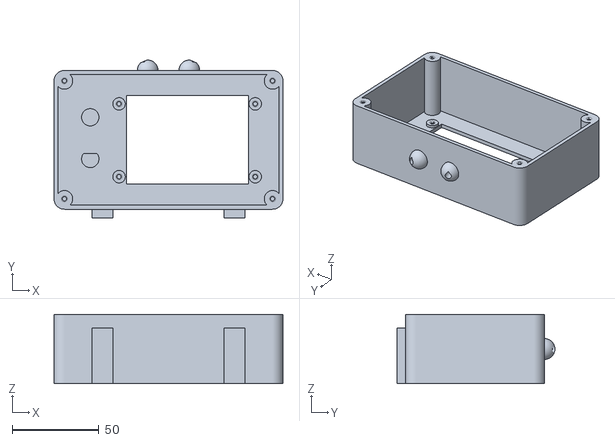
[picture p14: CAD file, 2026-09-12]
enclosure/prototype_v3/housing.stl
132.0 x 91.0 x 40.0

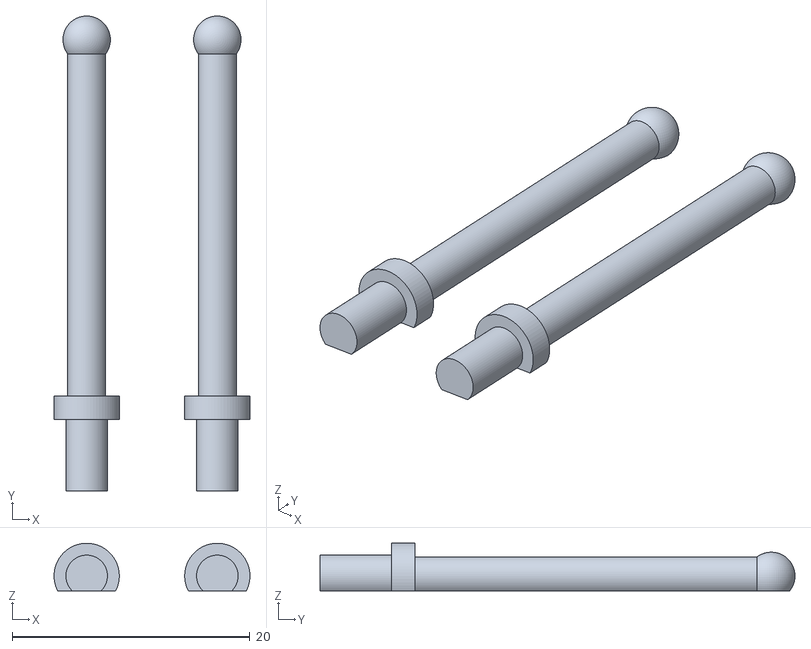
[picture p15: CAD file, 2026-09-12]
enclosure/prototype_v3/antennas.stl
16.5 x 40.0 x 4.00

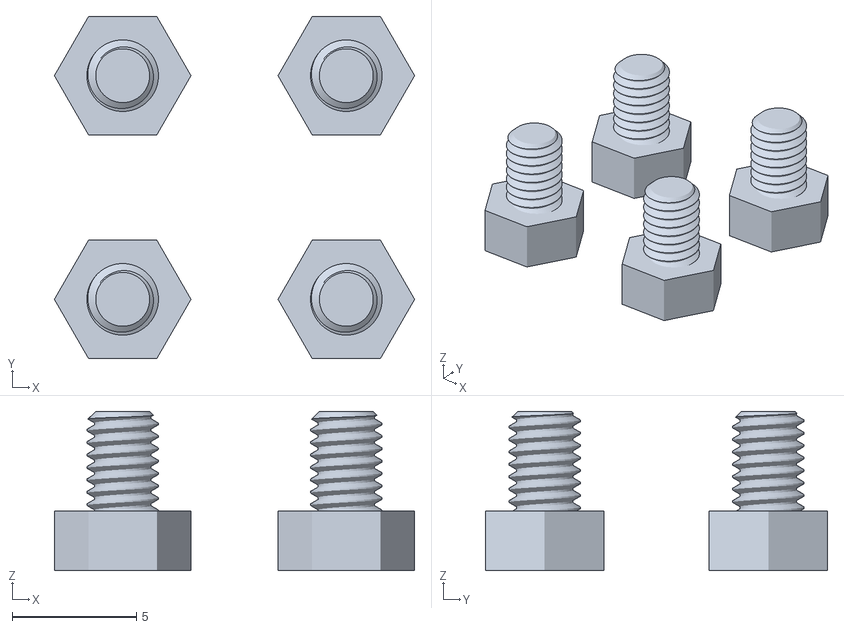
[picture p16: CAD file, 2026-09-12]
enclosure/prototype_v3/slotted_screws/pcb_screws_m3x4.stl
14.5 x 13.8 x 6.40

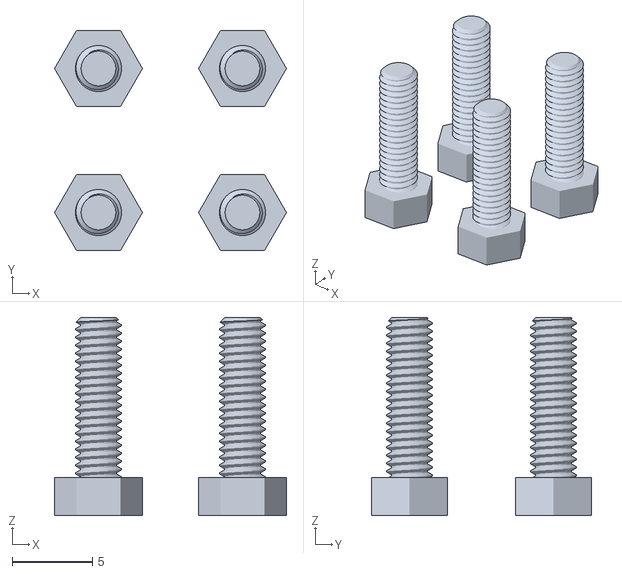
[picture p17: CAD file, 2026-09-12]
enclosure/prototype_v3/slotted_screws/back_screws_m3x10.stl
14.5 x 13.8 x 12.4

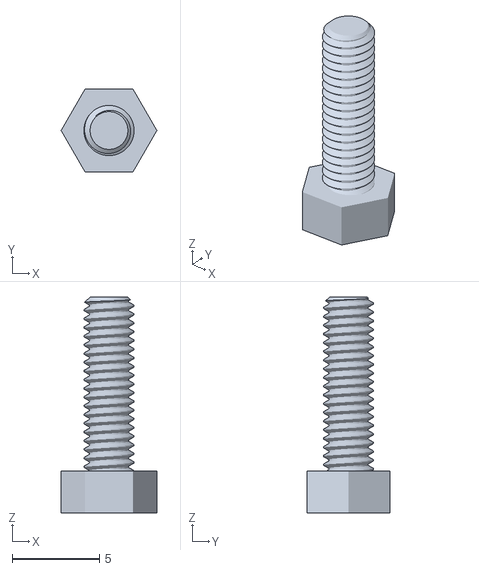
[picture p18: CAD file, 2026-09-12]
enclosure/prototype_v3/slotted_screws/test_screw.stl
5.50 x 4.76 x 12.4

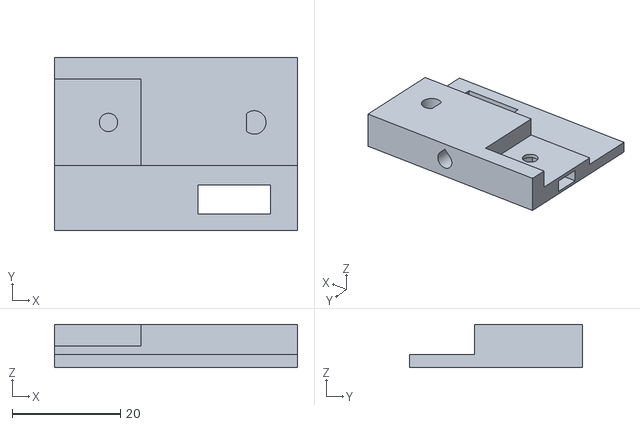
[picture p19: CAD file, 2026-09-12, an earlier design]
enclosure/prototype_v2/fit_coupon.stl
45.0 x 32.0 x 8.00

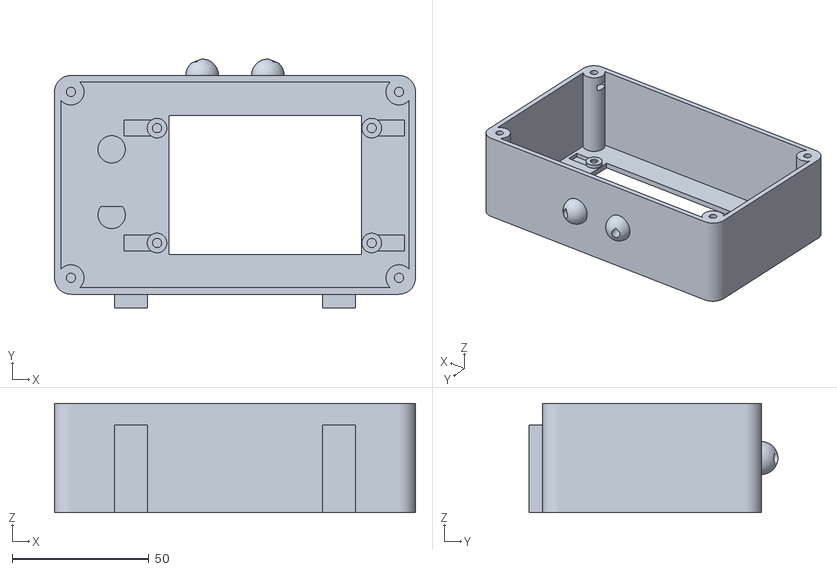
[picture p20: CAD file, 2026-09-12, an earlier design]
enclosure/prototype_v2/housing.stl
132.0 x 91.0 x 40.0

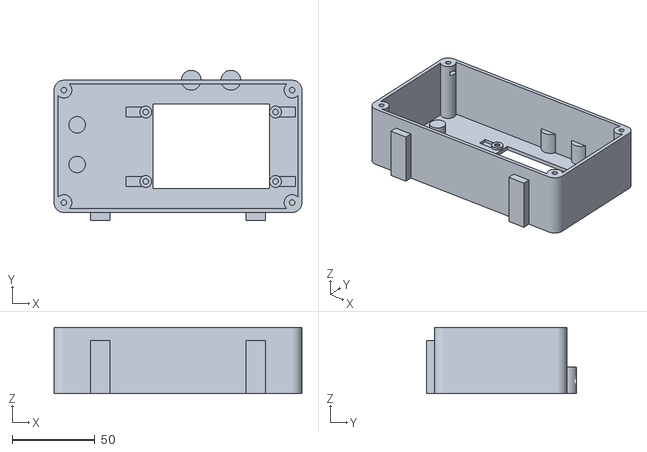
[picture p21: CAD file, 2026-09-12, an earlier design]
enclosure/prototype_v1/housing.stl
150.0 x 91.0 x 40.0

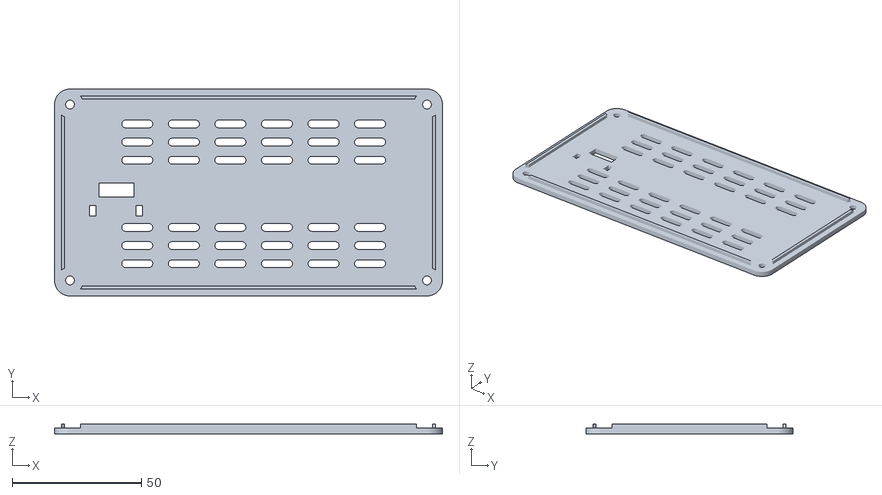
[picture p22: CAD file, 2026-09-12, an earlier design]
enclosure/prototype_v1/back_cover.stl
150.0 x 80.0 x 4.00

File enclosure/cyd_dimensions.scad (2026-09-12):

// ESP32-2432S028R reference based on physical board measurements, millimeters.
// Coordinate origin: lower-left PCB corner viewed from the display side.
// X follows the 86 mm edge, Y follows the 50.5 mm edge; +Z faces the display.
// Nominal reference values; see verification flags for measurements on this unit.
// Measured edge-to-edge on a sample board; overrides manufacturer 86 x 50.
pcb_width = 86.0;
pcb_height = 50.5;
pcb_outline_verified = true;
mount_hole_diameter = 3.2;
// Four-hole layout accepted after a successful physical alignment print.
// Right margin 3.5 and top margin 4.5, not all margins 4.
mount_origin = [4,4];
mount_hole_centers = [for (y = [0,42]) for (x = [0,78.5])
                     [mount_origin[0]+x,mount_origin[1]+y]];
active_display_size = [57.6,43.2]; // Illuminated area ONLY, not frame size.
// Earlier 70 x 51 frame / flush edges conflict with latest PCB measurements.
display_frame_outline = undef;
display_frame_xy = undef;
display_frame_outline_verified = false;

// Corrected hole center spacing from a physical sample board.
mount_center_spacing = [78.5,42.0];
mount_center_spacing_verified = true;
// Spacing confirmation alone does not measure diameter or offsets from PCB edges.
mount_edge_offsets_verified = true; // Physical gauge fit, not caliper precision.
mount_hole_diameter_verified = false;
mounting_pattern_verified = mount_center_spacing_verified &&
                            mount_edge_offsets_verified && mount_hole_diameter_verified;

// Leave these undefined until verified on the actual dual-USB board.
pcb_thickness = 1.0;
glass_above_pcb_front = 4.0;
fit_test_opening = [70.0,50.5]; // Accepted opening; not a glass precision measurement.
fit_test_opening_xy = [8.0,0.0];
display_frame_size = undef;       // [width,height,depth]
display_frame_position = undef;   // [x,y,z] lower-left/back of outer frame
active_display_position = undef;  // [x,y,z] lower-left of illuminated area
total_assembly_thickness = 11.0;
assembly_z_min = -6.0; // PCB + rear components = 7 mm; PCB itself = 1 mm.

// Each opening is [x,y,z,width,height,depth] in board coordinates.
// Include plug/finger/card travel clearance when sizing enclosure cutouts.
usb_c_cutout = undef;
micro_usb_cutout = undef;
microsd_access = undef;
boot_button_access = undef;
reset_button_access = undef;

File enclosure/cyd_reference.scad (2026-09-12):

// Open this file and press F5. No assumed USB/frame/button geometry is drawn.
include <cyd_dimensions.scad>

mode = "reference"; // "reference" = visual reference; "footprint" = exact 2D PCB
require_verified = false; // Keep false for reference work; true enforces known fit data.
$fn = 64;

// Rendering aids ONLY; neither is a measured physical thickness.
reference_sheet_thickness = 0.4;
reference_active_sheet_thickness = 0.2;

assert(pcb_width > 0 && pcb_height > 0 && mount_hole_diameter > 0);
if (!is_undef(display_frame_xy) && !is_undef(display_frame_outline))
assert(display_frame_xy[0] >= 0 && display_frame_xy[1] >= 0 &&
       display_frame_xy[0] + display_frame_outline[0] <= pcb_width &&
       display_frame_xy[1] + display_frame_outline[1] <= pcb_height,
       "Display frame outline extends beyond the measured PCB.");
assert(len(mount_hole_centers) == 4, "Expected four mounting holes.");
assert(mount_hole_centers[1][0] - mount_hole_centers[0][0] == mount_center_spacing[0] &&
       mount_hole_centers[3][0] - mount_hole_centers[2][0] == mount_center_spacing[0] &&
       mount_hole_centers[2][1] - mount_hole_centers[0][1] == mount_center_spacing[1] &&
       mount_hole_centers[3][1] - mount_hole_centers[1][1] == mount_center_spacing[1],
       "Hole coordinates must agree with the recorded center spacing.");
for (p = mount_hole_centers)
    assert(p[0] >= mount_hole_diameter/2 &&
           p[0] <= pcb_width - mount_hole_diameter/2 &&
           p[1] >= mount_hole_diameter/2 &&
           p[1] <= pcb_height - mount_hole_diameter/2,
           "Mounting hole crosses a PCB edge.");

if (require_verified) {
    assert(mounting_pattern_verified, "Verify mounting holes on actual USB-C revision first.");
    assert(!is_undef(pcb_thickness) && !is_undef(display_frame_size) &&
           !is_undef(display_frame_position) && !is_undef(active_display_position) &&
           !is_undef(total_assembly_thickness) && !is_undef(assembly_z_min) &&
           !is_undef(usb_c_cutout) && !is_undef(micro_usb_cutout) &&
           !is_undef(microsd_access) && !is_undef(boot_button_access) &&
           !is_undef(reset_button_access), "Fit-critical parameters remain unverified.");
}

module cyd_pcb_footprint() {
    difference() {
        square([pcb_width, pcb_height]);
        for (p = mount_hole_centers)
            translate(p) circle(d = mount_hole_diameter);
    }
}

module access_reference(box) {
    if (!is_undef(box))
        color([1,0.4,0,0.45])
            translate([box[0],box[1],box[2]]) cube([box[3],box[4],box[5]]);
}

module cyd_reference() {
    color("Goldenrod")
        linear_extrude(height = is_undef(pcb_thickness) ? reference_sheet_thickness : pcb_thickness)
            cyd_pcb_footprint();

    if (!is_undef(display_frame_size) && !is_undef(display_frame_position))
        color([0.35,0.35,0.35,0.6])
            translate(display_frame_position) cube(display_frame_size);
    else if (!is_undef(display_frame_xy) && !is_undef(display_frame_outline))
        // Measured XY outline only. Ring thickness/Z placement are visualization aids.
        color("DimGray")
            translate([display_frame_xy[0],display_frame_xy[1],
                       is_undef(pcb_thickness) ? reference_sheet_thickness : pcb_thickness])
                linear_extrude(height = reference_active_sheet_thickness)
                    difference() {
                        square(display_frame_outline);
                        translate([0.5,0.5])
                            square([display_frame_outline[0]-1,display_frame_outline[1]-1]);
                    }

    // With no measured position, show the active area BESIDE the PCB, not centered on it.
    color("SteelBlue")
        translate(is_undef(active_display_position) ? [pcb_width + 10,0,0] : active_display_position)
            cube([active_display_size[0],active_display_size[1],reference_active_sheet_thickness]);

    if (!is_undef(total_assembly_thickness) && !is_undef(assembly_z_min))
        color([0.2,0.8,0.7,0.15])
            translate([0,0,assembly_z_min])
                cube([pcb_width,pcb_height,total_assembly_thickness]);

    for (box = [usb_c_cutout,micro_usb_cutout,microsd_access,boot_button_access,reset_button_access])
        access_reference(box);
}

if (mode == "footprint") cyd_pcb_footprint();
else {
    assert(mode == "reference", "Choose reference or footprint mode.");
    cyd_reference();
}
echo("Provisional hole centers:", mount_hole_centers, "nominal diameter:", mount_hole_diameter);
echo("Measured PCB:", [pcb_width,pcb_height], "frame XY:", display_frame_outline, display_frame_xy);
echo("Hole edge offsets remain provisional pending physical alignment test.");
echo("USB-C revision mounting pattern verified:", mounting_pattern_verified);
echo("Actual board center spacing:", mount_center_spacing,
     "verified:", mount_center_spacing_verified);
if (is_undef(pcb_thickness)) echo("PCB is a 0.4 mm VISUAL sheet, not a measured thickness.");
if (is_undef(active_display_position)) echo("Blue active area is shown separately because its position is UNKNOWN.");

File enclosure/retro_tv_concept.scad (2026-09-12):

// MINI-TV: lesson 1 / appearance concept, NOT a fitted or print-ready enclosure.
// These are design placeholders, not measurements of a specific CYD board.
// Press F5 to preview. Change cabinet_width, save, and press F5 again.

cabinet_width = 120;   // millimeters, left to right
cabinet_height = 85;   // bottom to top
cabinet_depth = 40;    // back to front
wall = 2.4;
corner_radius = 7;

// Placeholder screen opening. Actual active area and PCB offsets need measuring.
screen_width = 64;
screen_height = 48;
screen_left = 12;
screen_bottom = 25;
knob_radius = 7;
knob_x = cabinet_width - 18;
antenna_length = 24;
antenna_splay = 12;
antenna_diameter = 2.8;
antenna_base_radius = 4;

$fn = 48; // Number of segments used to approximate curves.
epsilon = 0.05;

assert(cabinet_width >= 110, "Keep width at least 110 mm for this concept layout.");
assert(cabinet_height >= 80 && cabinet_depth >= 15);

// A module is a reusable shape, similar to a function in our C++ firmware.
module rounded_box(width, height, depth, radius) {
    hull() {
        for (x = [radius, width - radius])
            for (y = [radius, height - radius])
                translate([x, y, 0])
                    cylinder(h = depth, r = radius);
    }
}

module cabinet() {
    difference() {
        rounded_box(cabinet_width, cabinet_height, cabinet_depth, corner_radius);

        // Subtract the rear cavity, leaving walls and a front panel.
        translate([wall, wall, -epsilon])
            rounded_box(cabinet_width - 2 * wall,
                        cabinet_height - 2 * wall,
                        cabinet_depth - wall + epsilon,
                        corner_radius - wall);

        // Subtract the screen opening through the front panel.
        translate([screen_left, screen_bottom, cabinet_depth - wall - epsilon])
            rounded_box(screen_width, screen_height, wall + 2 * epsilon, 3);
    }
}

module knob(y) {
    color("SaddleBrown")
        translate([knob_x, y, cabinet_depth - epsilon])
            cylinder(h = 5, r = knob_radius);
    color("Wheat")
        translate([knob_x - 0.8, y, cabinet_depth + 4.9])
            cube([1.6, knob_radius - 1, 0.5]);
}

color("BurlyWood") cabinet();
knob(61);
knob(37);

// Short feet overlap the lower cabinet wall; attachment details come later.
for (x = [22, cabinet_width - 34])
    color("SaddleBrown")
        translate([x, -7, 5])
            cube([12, 9, cabinet_depth - 10]);

// Decorative rabbit-ear antennas. +Y is the top edge of the TV.
// These are visual concepts; separate printable parts/sockets will come later.
for (side = [-1,1]) {
    base = [cabinet_width/2 + side*5, cabinet_height - 1, cabinet_depth/2];
    tip = [base[0] + side*antenna_splay, base[1] + antenna_length, base[2]];
    color("SaddleBrown") translate(base) sphere(r = antenna_base_radius);
    color("Silver") hull() {
        translate(base) sphere(d = antenna_diameter);
        translate(tip) sphere(d = antenna_diameter);
    }
}

// The dark screen is only a visual placeholder, not a part to print.
if ($preview)
    color([0.08, 0.12, 0.14])
        translate([screen_left, screen_bottom, cabinet_depth - 1])
            rounded_box(screen_width, screen_height, 0.3, 3);

echo("CONCEPT ONLY: board mounts, port/button access, and rear closure are pending measurements.");

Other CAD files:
enclosure/prototype_v3/mini_tv.scad
enclosure/cyd_alignment_test.scad
enclosure/prototype_v1/mini_tv.scad
enclosure/prototype_v2/experimental_screws/back_screws_m3x10.stl
enclosure/prototype_v2/experimental_screws/nuts_m3_set_of_8.stl
enclosure/prototype_v2/experimental_screws/pcb_screws_m3x4.stl
enclosure/prototype_v2/experimental_screws/printed_nuts.scad
enclosure/prototype_v2/experimental_screws/printed_screws.scad
enclosure/prototype_v2/experimental_screws/test_nut.stl
enclosure/prototype_v2/experimental_screws/test_screw.stl
enclosure/prototype_v2/mini_tv.scad
enclosure/prototype_v3/preview_housing.scad
enclosure/prototype_v3/slotted_screws/screws.scad

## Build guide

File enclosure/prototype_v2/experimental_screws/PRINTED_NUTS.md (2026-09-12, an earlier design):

# Experimental printed nuts

Print `test_nut.stl` first. `nuts_m3_set_of_8.stl` contains all eight nuts:
four for the PCB supports and four for the rear-cover posts.

Each nut is 5.5 mm across flats and **2.0 mm tall**. Physical tests found
the original 2.4 mm nut too thick and the 1.4 mm revision slightly loose. This
revision follows a 1.7 mm trial and increases height to 2.0 mm,
retaining the width and thread pitch.
Reimport the updated STL and slice
at 100%; do not scale its height in the slicer, which would alter the pitch.
Existing pockets are nominally 5.8 mm across flats and 2.6 mm high in CAD. The
cause of the reduced physical slot clearance has not been established. Confirm
the actual pocket fit before assuming standard 2.4 mm metal nuts will fit.
The right-handed internal helix uses the existing printed screw's 0.5 mm pitch.
Its cutting profile is enlarged by 0.30 mm diametrally in XY only as an initial
print-fit allowance; this is not a certified M3 thread or a measured fit.
Small lead-in chamfers are provided on both faces.

Use the installed nozzle's profile, 100% scale, 0.08 mm layers, 100% infill,
and about 20 mm/s outer walls for a first trial. Print flat as supplied, with
the threaded hole vertical, supports off. These tiny threads may not resolve
well on a 0.4 mm nozzle. Inspect the sliced hole before printing. A brim can
help adhesion, but must be removed completely before testing the nut slot.

1. Try one printed nut on the printed test screw away from the electronics.
   Turn clockwise to tighten. Do not force it if the threads bind.
2. Try the nut in the original fit coupon's side-loading slot before inserting
   it into the case. The coupon's old cable aperture is unrelated to this test.
3. If both fits work, print the set of eight. Slide each nut into its slot and
   align its hole with the screw hole before assembling.
4. Use the 4 mm screws for the PCB and 10 mm screws only for the back cover.
   Tighten gently by hand. Avoid crushing or bending the PCB.

These parts are for prototype fit checks, not reliable final retention. Printed
threads can strip and printed nuts can split; the thinner nuts have less thread
engagement. Use metal M3 screws and metal nuts with verified pocket fit for the
final assembly. No strength or revised physical fit has been
verified by generating these files.

Source: `printed_nuts.scad`; it imports `printed_screws.scad`. Export with
`part="test"` or `part="eight"`, then use the existing `finish_stls.py` with
`test_nut nuts_m3_set_of_8` to clean microscopic export slivers.

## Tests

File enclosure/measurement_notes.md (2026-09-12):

# Measurement record (millimeters)

Latest correction, 2026-09-05: PCB 86 x 50.5; hole spacing 78.5 x 42.
Earlier bottom-left offset (4,4) is provisional. Derived right/top offsets are
3.5/4.5, pending alignment test. Hole diameter 3.2 is manufacturer nominal only.

Superseded readings: PCB 88 x 51; spacing 78 x 42.
Earlier frame: 70 x 51, left gap 10, right gap 8, flush top/bottom.
These cannot all hold with the latest PCB dimensions. Frame size/location are
undefined pending reconciliation; possible overhang must not be ruled out.
Earlier USB-C report: 19 to 29 from bottom-right corner, height 3. Edge direction,
Z position, cable plug size and bend clearance remain unverified.
PCB thickness, total assembly depth, active display position, SD/button access
remain unverified. No finished case fit is claimed.

Fit-test result: the 70 mm opening width and all four mounting holes align. The
original gauge's 8 mm top/bottom rails covered the display because its module is
flush with the PCB at those edges. The revised gauge moves its connecting bridges
outside the PCB and leaves a 70 x 50.5 mm full-height module opening.

User subsequently confirmed the revised test fits perfectly. The opening and
four-hole layout are accepted for the prototype. See prototype_requirements.md
for the flush-front design and the remaining depth/cable measurements.

## Full-prototype depth measurements supplied afterward

- Glass front is 4 mm above the PCB's front surface.
- PCB thickness is 1 mm.
- PCB plus rear connectors reach 7 mm, giving 11 mm total from glass to rear.
- USB-C exits right when viewing the display. Plugged cable extends at most
  30 mm beyond that PCB edge.
- Connector passage needs 13 mm width x 5 mm height; the plug must pass through
  first. V1 uses a closed 13.4 x 5.4 mm rear hole with 0.2 mm per-side allowance.
- V1 screen opening uses the fit-tested location and dimensions plus 0.2 mm
  per-side assembly clearance. Exact active-area position is still unknown and
  is not needed for the full-face flush opening.

Actual cable bend stiffness, rear component locations, board screw-head clearance
and enclosed temperature remain physical prototype checks.

## V2 confirmation (2026-09-06)

USB-C center is 24 mm above the PCB bottom when viewing the screen with the port
on the right (user confirmed). With the PCB's 14.75 mm bottom offset in the case,
that is Y=38.75. The 13 mm connector envelope is reserved about that center while
narrowing the knob compartment. Board dimensions and fitted hole layout are unchanged.

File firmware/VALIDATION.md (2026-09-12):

# Validation — 2026-09-08

## 2026-09-09: 1.0.2 TLS timeout diagnostics

Physical 1.0.1 testing confirms 4 MB flash, frame-memory self-test success and primary Wi-Fi
connection. It still fails TLS: attempts return -1 about 10 seconds after starting,
with roughly 23-26 KB heap remaining during the handshake. Unlike the earlier run,
this capture does not show an explicit allocation error. Inspected Arduino's SSL
implementation: its handshake deadline returns -1 without an mbedTLS error message.

Read-only Windows probes using TLS 1.2, without credentials or ALPN, reached both
resolved addresses (209.177.145.97 and 209.177.145.192), completed TLS in under one
second and received the expected HTTP 401 authentication challenge. This establishes
Windows reachability, not equivalence to the CYD's network or TLS implementation.
A separate DNS query to 1.1.1.1 returned NXDOMAIN; device-side DNS logging was added
to help resolve the discrepancy rather than assuming a route/certificate cause.

1.0.2 allows a 30-second TLS handshake and records safe connection diagnostics.
Certificate verification and Basic Auth remain enabled. Runtime success awaits
another physical test; do not treat this change alone as a confirmed fix.

## 2026-09-09 correction: 1.0.1

The physical 1.0.0 test failed HTTPS handshakes with SSL allocation error -32512
while approximately 78 KB of byte RAM remained. A successful compile did not
establish adequate runtime TLS memory. 1.0.1 moves frame storage into available
IRAM before falling back to DRAM. All IRAM accesses use volatile aligned 32-bit
loads/stores; small byte buffers bridge network, SHA-256, cache and display calls.
The 320x240 RGB565 format, server endpoints, certificate checks, cache records and
partition map are unchanged. Failed/empty frame polls now wait at least five seconds.

Every allocated block is checked at startup for fragmented copies, odd offsets,
surrounding-byte preservation and end-of-block handling. This self-test and actual
TLS headroom must be confirmed in the next physical run; a new upload is required.
The memory access constraints follow [Espressif's allocation documentation](https://docs.espressif.com/projects/esp-idf/en/v4.4.8/esp32/api-reference/system/mem_alloc.html).

Production `cyd_st7789` compile passed: 1,030,157 bytes program flash in the
1,769,472-byte slot and 47,972 bytes static RAM. No physical upload was performed
by the agent; successful HTTPS and slideshow playback still await the user's test.

The following results describe the original 1.0.0 build, not the correction.

Prepared firmware 1.0.0 (numeric release 10000) for the ST7789 remote TV and portal
2.2.0. These are local software results, not a claim of successful hardware deployment.

## Passed

- PlatformIO `cyd_st7789` production build using the existing local settings:
  1,028,917 bytes program flash out of a 1,769,472-byte OTA slot; 47,332 bytes static
  RAM out of 327,680. No credentials were changed.
- PlatformIO `cyd_st7789_check` example-settings build:
  1,028,845 bytes program flash; 47,332 bytes static RAM.
- 16 portal tests: the existing 12 checks plus device authentication/enablement,
  RGB565 dimensions/byte order/digest, catalogue next/wrap/reorder/deletion behavior,
  and firmware route isolation between device accounts.
- Four release-tool tests: valid signing and altered metadata rejection; rejection
  of wrong device/version/check binaries; preserving an existing signing identity;
  and non-overlapping 4 MB partitions with equal OTA slots and enough cache space.
- Inspected the linked ELF: `verifyRollbackLater` is the strong C-linkage override,
  so Arduino's early automatic confirmation is replaced by the player self-test.

The touchscreen warning is expected: this firmware does not use touch input.
Static RAM figures do not include the dynamically allocated 153600-byte image
buffer, network stack, worker stack and TLS allocations.

## Not yet tested

- Actual board flash capacity, boot with the new partition table, frame colors and
  orientation, TLS peak memory, Wi-Fi fallback/reconnection and sustained playback.
- Installing an OTA on the physical device; interrupted download/write, invalid
  new boot, watchdog reset, rollback and offline-cache power-loss behavior.
- The updated portal image under Docker/NGINX on the Ubuntu VM. Docker is not
  installed on this Windows host. Portal tests ran locally with Flask/Pillow.
- Connectivity from the secondary Wi-Fi. No server credentials or network
  settings were exercised against the live site during this build.

Follow DEPLOYMENT.md before treating the remote unit as ready for unattended use.

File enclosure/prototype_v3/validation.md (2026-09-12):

# V3 checks — 2026-09-07

Follow-up testing found that the screws tighten well, but the Allen-key
recess slips. The optional `slotted_screws` revision changes the drive head
while reusing the successful threaded shaft. Its physical head fit remains
to be tested. The original CAD checks below are retained as history.

- Housing: one closed, consistently wound mesh; 94,150 triangles; positive
  volume 67,164.2 mm³; bounds 132 x 90.9928 x 40 mm, bed Z=0.
- Coupon: one closed mesh; 22,060 triangles; bounds 34 x 16 x 12 mm.
- Test spacers: two closed bodies; bounds 25.5 x 11 x 2.4 mm.
- All six delivered STL files pass topology, winding, positive-volume,
  connected-body, print-bed and dimensional checks.
- Ray intersections against the actual exported housing and coupon verify
  all ten holes' 0.5 mm pitch, right-handed direction and blind depth.
  PCB hole depth is 3.4 mm; rear hole depth is 8.2 mm.
- Source assertions retain the flush glass plane and confirm screw-tip gaps.
- The back cover, knobs and antennas match the latest V2 STLs byte for byte.
- The thread-coupon preview and exported-housing rear view were inspected.
- Numerical export cleanup moved no housing vertex more than 0.00002 mm.

No new physical fit, clamp-load or durability test has been performed. The
coupon/spacer trial is required to establish printed screw fit, especially at
the requested 0.20 mm layers. The previous fastener failure's cause is unproven.
Full assembly collision checks from V2 were not rerun for V3; thread direction,
depth and unchanged accessory geometry were checked as described above.

`preview_housing.scad` provides a fast view of the exported mesh. The editable
source evaluates detailed thread cutters for F5 and may take over a minute;
a full F6/CLI housing export took about seven minutes on this machine.

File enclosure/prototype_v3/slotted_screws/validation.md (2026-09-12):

# Slotted screw checks — 2026-09-08

All three STLs pass closed-manifold, consistent-winding, positive-volume,
nondegenerate-face, bed-placement and connected-body checks. Test file has
one screw; PCB/back sets each have four. Heights are 12.4 mm for the test/back
screws and 6.4 mm for PCB screws, retaining 2.4 mm head height.

Ray checks verify each of the nine screws' slot interior, boundary and 1.2 mm
depth. Sampled shaft surfaces at 24 angle/height combinations per screw,
including the tapered tip, match the old exports within 0.001 mm (reported
maximum discrepancy rounds to 0.00000000 mm). The shaft module is imported
directly from the unchanged original source.

Head maximum diameter remains 5.5 mm; across flats is 4.7631 mm. The head preview
was visually inspected. CAD-export sliver cleanup moved vertices by no more
than 0.0000142 mm. Housing files and existing screw files were not modified.

Physical screwdriver fit and resistance to stripping remain untested. Testing
confirmed the original threads tighten well; this revision changes only heads.

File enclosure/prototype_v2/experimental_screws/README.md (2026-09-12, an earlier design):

# Experimental printed screws

These are trial parts for learning and checking whether your printer can resolve
the thread. They have not been physically tested or strength-rated. Real metal
M3 screws remain the recommended fasteners for the finished TV, especially the
PCB. Tiny printed threads and heads can strip or snap under tightening.

The case still requires its eight METAL M3 nuts. These files replace neither
those nuts nor any housing parts. Keep the existing screw lengths unchanged.

| File | Contents | Under-head length | Total height |
| --- | --- | --- | --- |
| `test_screw.stl` | One trial screw; print this first | 10 mm | 12.4 mm |
| `pcb_screws_m3x4.stl` | Four experimental PCB screws | 4 mm | 6.4 mm |
| `back_screws_m3x10.stl` | Four experimental back-cover screws | 10 mm | 12.4 mm |

The head is 5.5 mm diameter x 2.4 mm tall, with a 2.1 mm hex recess intended for
a 2 mm key. Screw length is measured from the head's bearing surface to the tip,
not from the top of the head. This preserves the PCB screw's depth limit.

## First print and fit check

1. Import only `test_screw.stl` into Bambu Studio. Keep its head on the plate and
   shaft upright, at 100% scale. No supports on the threads.
2. With your installed nozzle profile, use a fine layer height such as 0.08 mm
   if supported, rather than the 0.20 mm used for the case. Start with PLA,
   100% infill and a slow outer-wall speed (around 20 mm/s). Use a small brim
   if necessary for adhesion. These are trial settings, not a verified recipe.
3. Inspect the sliced preview: a 0.5 mm pitch needs recognizable separate thread
   turns. After printing and cooling, remove stray filament without crushing it.
4. Try it by hand in a LOOSE metal M3 nut, away from the PCB and the housing's
   captive pockets. It should turn through the nut smoothly with light force.
   Do not use a drill, pliers or a driver to force a poor fit.
5. If it binds, breaks or spins without engaging, do not use it in the case.
   Metal M3 x 4 / M3 x 10 screws are the straightforward reliable option.
6. Only after a successful loose-nut trial, consider the pair of four-screw files
   for a gentle experimental assembly. Use minimal tightening force and check
   the head's component clearance. Never put the 10 mm screws through the PCB.

A smaller nozzle may improve detail but does not establish fastener strength.
The test screw's fit alone is not a load test. I recommend metal screws for
holding the actual board even if these trial screws appear to work.

## Geometry and adjustment

`printed_screws.scad` is self-contained. The model has a single-start right-hand
helix, 0.5 mm pitch, truncated 60-degree flanks and a short tip taper. The root
is simplified and flat rather than a production screw's rounded root.

[Bossard's metric thread table](https://www.bossard.com/-/media/bossard-group/website/documents/technical-resources/en/f-079-en.pdf)
lists M3 coarse pitch as 0.5 mm and the 6g maximum major diameter as 2.980 mm.
The model subtracts a trial **0.10 mm diametral print compensation**, giving a
2.88 mm modeled major diameter. This is not a claim of ISO tolerance compliance.
Actual printed fit depends on extrusion, cooling and material.

If a loose-nut test justifies a small adjustment, change `diameter_compensation`
(0 to 0.20 mm allowed) and regenerate a single test. Increasing it makes the
thread smaller and weaker; decreasing it makes it larger. Do NOT scale the STL:
scaling would change pitch and screw length as well as diameter.

In OpenSCAD choose `part="test"`, `"pcb"` or `"back"`, press F6, then export STL.
The supplied files also receive numerical mesh finishing and verification;
`build.ps1` repeats the complete export/finish/check workflow. Finishing merges
CAD-export edges shorter than 0.00003 mm, without rescaling or smoothing threads.
Use the supplied STLs directly for printing.
These are standalone experimental files and do not change the V2 case or the
main print instructions recommending metal hardware.
# Printed nut fit tests

Optional experimental printed nuts are now available: see
[PRINTED_NUTS.md](PRINTED_NUTS.md) for the single test nut and eight-nut STL.
The metal-hardware recommendations below still apply to final assembly.

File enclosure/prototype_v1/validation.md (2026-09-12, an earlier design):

# Prototype V1 validation

OpenSCAD rendered the five printable exports as simple solids. Independent STL
checks confirmed that every mesh edge has two incident faces, winding is
consistent, volumes are positive, no degenerate triangles exist, and the lowest
Z coordinate is zero. The pair exports intentionally contain two bodies.

| Part | Bodies | Measured STL bounding box, mm |
| --- | ---: | --- |
| Housing | 1 | 150 x 91 x 40 |
| Back cover | 1 | 150 x 80 x 4 |
| Knobs | 2 | 36.9374 x 15.9374 x 10 |
| Antennas | 2 | 16.5 x 39.9976 x 4 |
| Fit coupon | 1 | 45 x 32 x 8 |

Knurling and faceted circular tips account for the small differences from nominal
part bounding dimensions. Preview images were inspected for assembly placement,
the flush display face, separate accessories, internal mounts and rear openings.

The modeled housing-versus-board/cover/accessory intersection was empty after
allowing 0.01 mm at intentional seating contacts. OpenSCAD's exit code 1 with
"Current top level object is empty" is the expected passing result for this
intersection export. The final board-nut entry slots were subsequently lengthened
by removing more material, which cannot introduce a new overlap with those parts.

Measured inputs: PCB 86 x 50.5; accepted hole pitch 78.5 x 42; accepted aperture
70 x 50.5; glass projection 4; PCB thickness 1; overall assembly depth 11; right
USB-C plug projection 30; connector passage envelope 13 x 5.

The virtual component model does not contain the actual connector/component
shapes or screw heads. Physical tests must confirm PCB screw access, cable bend,
actual peg/nut fits and operating temperature. Geometry checks do not establish
those measurements or constitute a completed physical test of this prototype.

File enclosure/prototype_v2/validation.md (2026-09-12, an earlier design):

# V2 validation

## Cable-opening revision after the first full print

Physical testing found a good overall fit, with the rear cable opening too short.
The regenerated back cover increases only that opening from 13.4 x 5.4 to
13.4 x 8.4 mm at the same center. Its STL aperture corner coordinates were
checked directly. The mesh passes closed-manifold, winding, positive-volume,
single-body and bed-placement checks: 12,104 triangles, bounds 132 x 80 x 4 mm.
The updated rear preview was inspected. Housing, original fit coupon, knobs,
antennas and hardware geometry are unchanged. The enlarged opening still needs
a physical connector fit test. The historical validation below predates this change.

## Original V2 checks

Independent STL checks passed: closed manifold edges, consistent winding,
positive volume, no degenerate faces, correct connected-part counts and bed Z=0.

| Part | Connected bodies | STL bounds (mm) |
| --- | ---: | --- |
| Housing | 1 | 132 x 90.9928 x 40 |
| Back cover | 1 | 132 x 80 x 4 |
| Knobs | 2 | 36.9374 x 15.9374 x 10 |
| Antennas | 2 | 16.5 x 39.9976 x 4 |
| Fit coupon | 1 | 45 x 32 x 8 |

Housing height includes the unchanged 5 mm feet and the 6 mm dome rise. The
0.0072 mm difference from nominal height is the sphere mesh's faceting.

V1/V2 knob, antenna and fit-coupon STL SHA-256 hashes match exactly.
Source assertions check equal 12.9 mm knob-edge gaps, centered domes, retained
PCB/glass depths, rear-hole placement, 2.4 mm minimum vent webs and 0.8 mm minimum
wall at the local lower-knob relief. Actual remaining socket wall is 0.825 mm.

Assembly/front, housing-interior and rear-cover previews were inspected. The
rear design retains 36 slots of 12 x 3 mm, with the same row heights; hole/slot
sizes and all fastener dimensions are preserved while horizontal layout narrows.

The modeled housing intersection with the board, back, knobs, antenna rods and
connector envelope was empty. The separate plug-versus-knobs intersection was
also empty. Intended seating contacts were separated by 0.01 mm during this
check to avoid coplanar artifacts. OpenSCAD exit code 1 with "Current top level
object is empty" is the expected passing result of the intersection export.

Physical fit, plug/cable flexibility, support removal and temperature remain
prototype checks. The hemisphere undersides require local print supports.

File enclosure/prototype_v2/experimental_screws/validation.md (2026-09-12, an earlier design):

# Experimental screw geometry checks

All three delivered binary STLs passed closed-manifold, winding, positive-volume,
zero-degenerate-face, connected-part and print-bed placement checks.

| File | Bodies | Bounds, mm |
| --- | ---: | --- |
| test_screw.stl | 1 | 5.5 x 5.5 x 12.4 |
| pcb_screws_m3x4.stl | 4 | 14.5 x 14.5 x 6.4 |
| back_screws_m3x10.stl | 4 | 14.5 x 14.5 x 12.4 |

Head thickness is 2.4 mm; this leaves the required 4 and 10 mm under-head lengths.
Ray checks on the exported test screw confirm a 2.88 mm crest diameter at two
successive 0.5 mm pitch positions. A crest advances 0.125 mm axially through a
positive 90-degree turn, confirming right-handed geometry. The opposite phase
matches the modeled 2.26657 mm core diameter.

Numerical finishing collapsed microscopic short edges introduced by CAD Boolean
intersections and ASCII precision. Maximum vertex displacement was approximately
0.00001415 mm. The supplied files are then saved as binary STL and independently
checked. This is mesh cleanup only, not a physical tolerance or strength claim.

No physical print, metal-nut fit, torque, fatigue or load test has been performed.
These are experimental specimens; metal screws remain recommended for final use.

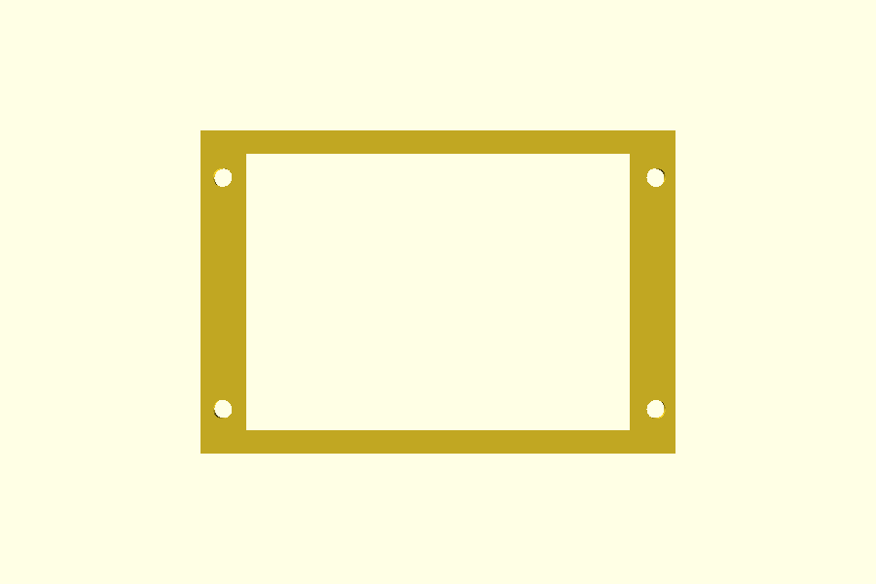
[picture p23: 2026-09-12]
enclosure/cyd_screen_fit_test.png

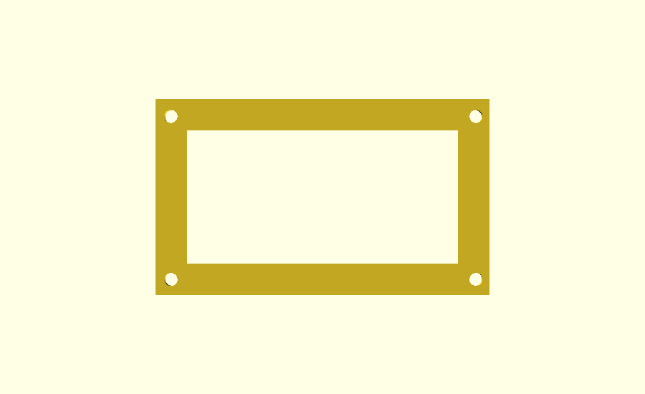
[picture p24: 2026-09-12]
enclosure/cyd_alignment_test.png

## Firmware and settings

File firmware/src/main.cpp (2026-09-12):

#include <Arduino.h>
#include <TFT_eSPI.h>
#include <WiFi.h>
#include <esp_system.h>
#include <esp_task_wdt.h>
#include "tv_settings.h"
#include "server_connection.h"
#include "player.h"
#include "firmware_version.h"
#define MINI_TV_STRINGIFY_INNER(x) #x
#define MINI_TV_STRINGIFY(x) MINI_TV_STRINGIFY_INNER(x)
const char kReleaseMarker[] = "MINITV:" MINI_TV_HARDWARE ":" MINI_TV_STRINGIFY(MINI_TV_VERSION);
constexpr char userCharacter(size_t i) { return i < sizeof(TV_SERVER_USER) ? TV_SERVER_USER[i] : '\0'; }
const char kDeviceMarker[] = {'M','I','N','I','T','V','D','E','V','I','C','E',':',
  userCharacter(0), userCharacter(1), userCharacter(2), userCharacter(3), userCharacter(4),
  userCharacter(5), userCharacter(6), userCharacter(7), userCharacter(8), '\0'};

#ifndef MINI_TV_TFT_SETUP
#error "Project TFT setup was not injected by PlatformIO"
#endif

namespace {
TFT_eSPI tft;
constexpr uint8_t kRotation = 1;
constexpr uint32_t kHeartbeatMs = 5000;
uint32_t lastHeartbeat = 0;

// Each connection attempt gets 20 seconds, followed by 10 seconds before retrying.
constexpr uint32_t kWifiTimeoutMs = 20000;
constexpr uint32_t kWifiRetryMs = 10000;
enum class WifiState { Disabled, Connecting, Connected, Waiting };
WifiState wifiState = WifiState::Disabled;
uint32_t wifiStateStarted = 0;
struct WifiNetwork { const char* name; const char* password; const char* label; };
const WifiNetwork networks[] = {
    {REMOTE_WIFI_SSID, REMOTE_WIFI_PASSWORD, "secondary"},
    {WIFI_SSID, WIFI_PASSWORD, "primary"},
};
size_t networkIndex = 0;

const char* wifiStateName() {
  switch (wifiState) {
    case WifiState::Connecting: return "connecting";
    case WifiState::Connected: return "connected";
    case WifiState::Waiting: return "waiting to retry";
    default: return "disabled";
  }
}

void scheduleWifiRetry() {
  // Cancel the current attempt, but leave the station interface enabled.
  WiFi.disconnect();
  const size_t other = 1 - networkIndex;
  if (networks[other].name[0] != '\0') networkIndex = other;
  wifiState = WifiState::Waiting;
  wifiStateStarted = millis();
  Serial.println("[WiFi] Retrying in 10 seconds; the photo stays on screen.");
}

void connectWifi() {
  Serial.printf("[WiFi] Connecting to %s network... (20-second timeout)\n", networks[networkIndex].label);
  if (!WiFi.mode(WIFI_STA)) {
    Serial.println("[WiFi] Could not start station mode.");
    scheduleWifiRetry();
    return;
  }
  wifiState = WifiState::Connecting;
  wifiStateStarted = millis();
  // begin() starts the attempt. We check its progress in loop(), not a while loop.
  // Its return value can still reflect the previous attempt's asynchronous status.
  // Let updateWifi() observe success or the deadline instead of cancelling early.
  WiFi.begin(networks[networkIndex].name, networks[networkIndex].password);
}

void startWifi() {
  if (WIFI_SSID[0] == '\0' && REMOTE_WIFI_SSID[0] == '\0') {
    Serial.println("[WiFi] Disabled: enter your network details in include/secrets.h, then upload.");
    return;
  }
  WiFi.persistent(false);  // Keep connection settings in RAM instead of saving to NVS.
  WiFi.setAutoReconnect(false);  // This program owns the retry timing.
  WiFi.setHostname("mini-tv");
  networkIndex = REMOTE_WIFI_SSID[0] != '\0' ? 0 : 1;
  connectWifi();
}

void updateWifi() {
  if (wifiState == WifiState::Disabled) return;

  const uint32_t now = millis();
  if (wifiState == WifiState::Waiting) {
    // Unsigned subtraction also works when millis() wraps around.
    if (now - wifiStateStarted >= kWifiRetryMs) connectWifi();
    return;
  }

  const wl_status_t status = WiFi.status();
  if (status == WL_CONNECTED) {
    if (wifiState != WifiState::Connected) {
      wifiState = WifiState::Connected;
      Serial.println("[WiFi] Connected");
      Serial.print("[WiFi] IP address: ");
      Serial.println(WiFi.localIP());
      Serial.printf("[WiFi] Signal: %ld dBm\n", static_cast<long>(WiFi.RSSI()));
      server_connection::onWifiConnected();
    }
    return;
  }

  if (wifiState == WifiState::Connected) {
    Serial.printf("[WiFi] Connection lost (status=%d).\n", static_cast<int>(status));
    scheduleWifiRetry();
  } else if (now - wifiStateStarted >= kWifiTimeoutMs) {
    // Status alone cannot reliably distinguish every password/router/DHCP problem.
    Serial.printf("[WiFi] Timed out (status=%d). Check SSID, password, 2.4 GHz and signal.\n",
                  static_cast<int>(status));
    scheduleWifiRetry();
  }
}

struct ColorBlock {
  uint16_t color;
  uint16_t text;
  const char* label;
};

void printDiagnostics() {
  setup_t actual;
  tft.getSetup(actual);  // Compiled library settings, not hardware detection.
  Serial.println("\n=== Mini TV " MINI_TV_VERSION_NAME " ===");
  Serial.println(kReleaseMarker);
  Serial.println(kDeviceMarker);
#ifdef MINI_TV_USE_EXAMPLE_SETTINGS
  Serial.println("MINITV_CHECK_BUILD_DO_NOT_RELEASE");
#endif
  Serial.println("Startup screen: color test");
  Serial.printf("Build: %s %s\n", __DATE__, __TIME__);
  Serial.printf("Chip: %s rev %u, CPU: %u MHz\n", ESP.getChipModel(),
                ESP.getChipRevision(), ESP.getCpuFreqMHz());
  Serial.printf("Flash: %u bytes, free heap: %u bytes, reset reason: %d\n",
                ESP.getFlashChipSize(), ESP.getFreeHeap(),
                static_cast<int>(esp_reset_reason()));
  Serial.printf("TFT_eSPI: %s; setup: %s\n", TFT_ESPI_VERSION, USER_SETUP_INFO);
  Serial.printf("Selected panel: %s; library driver: 0x%04X\n",
                MINI_TV_PANEL_NAME, actual.tft_driver);
  Serial.printf("Library pins: MOSI=%d MISO=%d SCLK=%d CS=%d DC=%d RST=%d\n",
                actual.pin_tft_mosi, actual.pin_tft_miso, actual.pin_tft_clk,
                actual.pin_tft_cs, actual.pin_tft_dc, actual.pin_tft_rst);
  Serial.printf("Backlight: GPIO %d active HIGH; HSPI: %u Hz; SPI mode: %u\n",
                TFT_BL, SPI_FREQUENCY, TFT_SPI_MODE);
  Serial.println("Panel selection is configuration, NOT detected hardware identity.");
  Serial.println("Secure slideshow, offline snapshot and signed OTA updates.");
}

void drawColorTest() {
  const int16_t width = tft.width();
  const int16_t height = tft.height();
  const ColorBlock blocks[] = {
      {TFT_RED, TFT_WHITE, "RED"},
      {TFT_GREEN, TFT_BLACK, "GREEN"},
      {TFT_BLUE, TFT_WHITE, "BLUE"},
      {TFT_CYAN, TFT_BLACK, "CYAN"},
      {TFT_MAGENTA, TFT_BLACK, "MAGENTA"},
      {TFT_YELLOW, TFT_BLACK, "YELLOW"},
  };
  tft.fillScreen(TFT_BLACK);
  tft.setTextDatum(MC_DATUM);
  tft.setTextColor(TFT_WHITE, TFT_BLACK);
  tft.drawString("MINI TV", width / 2, 23, 4);

  constexpr int16_t top = 48;
  const int16_t bottom = height - 30;
  for (int i = 0; i < 6; ++i) {
    const int col = i % 3;
    const int row = i / 3;
    const int16_t x0 = col * width / 3;
    const int16_t x1 = (col + 1) * width / 3;
    const int16_t y0 = top + row * (bottom - top) / 2;
    const int16_t y1 = top + (row + 1) * (bottom - top) / 2;
    tft.fillRect(x0, y0, x1 - x0, y1 - y0, blocks[i].color);
    tft.setTextColor(blocks[i].text, blocks[i].color);
    tft.drawString(blocks[i].label, (x0 + x1) / 2, (y0 + y1) / 2, 2);
  }
  tft.setTextColor(TFT_WHITE, TFT_BLACK);
  tft.drawString("READY FOR SETUP", width / 2, height - 15, 2);
  tft.drawRect(0, 0, width, height, TFT_WHITE);
}
}  // namespace

void setup() {
  Serial.begin(115200);
  delay(600);  // Bounded startup delay; no dependency on an open monitor.
  printDiagnostics();
  pinMode(TFT_BL, OUTPUT);
  digitalWrite(TFT_BL, LOW);
  Serial.println("Initializing TFT...");
  tft.init();
  digitalWrite(TFT_BL, LOW);  // init() may enable the backlight.
  tft.setRotation(kRotation);
  Serial.printf("Logical display: %d x %d, rotation: %u\n",
                tft.width(), tft.height(), kRotation);
  const uint32_t started = micros();
  drawColorTest();
  digitalWrite(TFT_BL, TFT_BACKLIGHT_ON);
  Serial.printf("Display draw calls completed in %lu us. Visually verify the panel.\n",
                static_cast<unsigned long>(micros() - started));
  lastHeartbeat = millis();
  server_connection::begin();
  startWifi();
  esp_task_wdt_init(30, true);
  esp_task_wdt_add(nullptr);
}

void loop() {
  esp_task_wdt_reset();
  updateWifi();
  server_connection::update();
  player::drawReady(tft);
  const uint32_t now = millis();
  if (now - lastHeartbeat >= kHeartbeatMs) {
    lastHeartbeat = now;
    Serial.printf("[alive] uptime=%lu ms, free heap=%u bytes, frame=1, WiFi=%s\n",
                  static_cast<unsigned long>(now), ESP.getFreeHeap(), wifiStateName());
  }
  delay(10);
}

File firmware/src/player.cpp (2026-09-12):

#include <Arduino.h>
#include <WiFi.h>
#include <esp_partition.h>
#include <esp_heap_caps.h>
#include <mbedtls/sha256.h>
#include <time.h>
#include <atomic>
#include "player.h"
#include "secure_http.h"
#include "ota.h"
#include "word_storage.h"

namespace player {
namespace {
constexpr size_t kRows = 15, kBlock = 320 * kRows * 2, kBlocks = 240 / kRows;
constexpr size_t kBytes = kBlock * kBlocks, kSlot = 0x27000;
constexpr uint32_t kMagic = 0x4D545631;  // "MTV1"
uint32_t* blocks[kBlocks] = {};
// Only the display task uses this ordinary byte-accessible scanline.
alignas(4) uint16_t displayRow[320];
QueueHandle_t readyQueue = nullptr, freeQueue = nullptr;
bool displayed = false;
std::atomic<bool> serverVerified{false};
uint32_t lastDisplay = 0, sequence = 0, lastCache = 0;
int cacheSlot = -1;
String currentId, cachedId;
const esp_partition_t* cache = nullptr;
struct Record { uint32_t magic; uint32_t sequence; uint8_t digest[32]; char id[33]; };

void hashFrame(uint8_t* digest) {
  uint8_t scratch[1024];
  mbedtls_sha256_context hash;
  mbedtls_sha256_init(&hash);
  mbedtls_sha256_starts_ret(&hash, 0);
  for (auto block : blocks) {
    for (size_t offset = 0; offset < kBlock; offset += sizeof(scratch)) {
      const size_t amount = min(sizeof(scratch), kBlock - offset);
      loadWordBytes(block, offset, scratch, amount);
      mbedtls_sha256_update_ret(&hash, scratch, amount);
    }
  }
  mbedtls_sha256_finish_ret(&hash, digest);
  mbedtls_sha256_free(&hash);
}

bool loadSlot(int slot, Record& record) {
  uint8_t scratch[1024];
  if (esp_partition_read(cache, slot * kSlot, &record, sizeof(record)) != ESP_OK ||
      record.magic != kMagic || record.id[32] != '\0') return false;
  uint8_t id[16];
  if (!hexBytes(String(record.id), id, sizeof(id))) return false;
  for (size_t i = 0; i < kBlocks; ++i) {
    for (size_t offset = 0; offset < kBlock; offset += sizeof(scratch)) {
      const size_t amount = min(sizeof(scratch), kBlock - offset);
      if (esp_partition_read(cache, slot * kSlot + 4096 + i * kBlock + offset, scratch, amount) != ESP_OK)
        return false;
      storeWordBytes(blocks[i], offset, scratch, amount);
    }
  }
  uint8_t digest[32];
  hashFrame(digest);
  return memcmp(digest, record.digest, 32) == 0;
}

bool loadCache() {
  cache = esp_partition_find_first(ESP_PARTITION_TYPE_DATA, ESP_PARTITION_SUBTYPE_ANY, "tvcache");
  if (!cache || cache->size < kSlot * 2) return false;
  Record a{}, b{};
  bool validA = loadSlot(0, a), validB = loadSlot(1, b);
  if (!validA && !validB) return false;
  cacheSlot = validB && (!validA || b.sequence > a.sequence) ? 1 : 0;
  Record chosen{};
  if (!loadSlot(cacheSlot, chosen)) return false;
  sequence = chosen.sequence;
  cachedId = chosen.id;
  // Ask for the first picture on startup; the cached snapshot may be anywhere in the order.
  Serial.println("[Cache] Verified offline snapshot loaded.");
  return true;
}

void saveCache() {
  if (!cache || cachedId == currentId ||
      (cacheSlot >= 0 && millis() - lastCache < 6UL * 60 * 60 * 1000)) return;
  const int target = cacheSlot == 0 ? 1 : 0;
  uint8_t scratch[1024];
  Record record{};
  record.magic = kMagic;
  record.sequence = sequence + 1;
  hashFrame(record.digest);
  currentId.toCharArray(record.id, sizeof(record.id));
  if (esp_partition_erase_range(cache, target * kSlot, kSlot) != ESP_OK) return;
  for (size_t i = 0; i < kBlocks; ++i) {
    for (size_t offset = 0; offset < kBlock; offset += sizeof(scratch)) {
      const size_t amount = min(sizeof(scratch), kBlock - offset);
      loadWordBytes(blocks[i], offset, scratch, amount);
      if (esp_partition_write(cache, target * kSlot + 4096 + i * kBlock + offset, scratch, amount) != ESP_OK)
        return;
    }
  }
  // Commit metadata last. An interrupted write leaves the other slot intact.
  if (esp_partition_write(cache, target * kSlot, &record, sizeof(record)) != ESP_OK) return;
  cacheSlot = target;
  sequence = record.sequence;
  cachedId = currentId;
  lastCache = millis();
  Serial.println("[Cache] Offline snapshot saved.");
}

bool fetchFrame() {
  uint8_t scratch[1024];
  WiFiClientSecure tls;
  HTTPClient http;
  if (!prepareHttp(http, tls, "/device/next?after=" + currentId)) return false;
  const char* headers[] = {"X-Photo-ID", "X-Frame-SHA256"};
  http.collectHeaders(headers, 2);
  const uint32_t requestStarted = millis();
  int code = http.GET();
  reportHttpAttempt("frame", code, requestStarted, tls);
  if (code == 204) { serverVerified = true; http.end(); return false; }
  uint8_t id[16], expected[32];
  String nextId = http.header("X-Photo-ID");
  bool good = code == 200 && http.getSize() == static_cast<int>(kBytes) &&
      hexBytes(nextId, id, sizeof(id)) && hexBytes(http.header("X-Frame-SHA256"), expected, 32);
  size_t received = 0;
  uint32_t started = millis(), active = started;
  auto* stream = http.getStreamPtr();
  while (good && received < kBytes) {
    int available = stream->available();
    if (available > 0) {
      size_t amount = min(sizeof(scratch), min(static_cast<size_t>(available), kBlock - received % kBlock));
      int count = stream->read(scratch, amount);
      if (count <= 0) { good = false; break; }
      storeWordBytes(blocks[received / kBlock], received % kBlock, scratch, count);
      received += count;
      active = millis();
    } else {
      if (!stream->connected() || millis() - active > 5000) good = false;
      vTaskDelay(pdMS_TO_TICKS(10));
    }
    if (millis() - started > 60000) good = false;
  }
  http.end();
  if (good) {
    uint8_t actual[32];
    hashFrame(actual);
    good = memcmp(actual, expected, 32) == 0;
  }
  if (good) { currentId = nextId; serverVerified = true; }
  else Serial.printf("[Player] Frame unavailable or incomplete (HTTP %d); keeping current picture.\n", code);
  return good;
}

void heartbeat() {
  WiFiClientSecure tls;
  HTTPClient http;
  if (!prepareHttp(http, tls, "/device/heartbeat")) return;
  const uint32_t requestStarted = millis();
  int code = http.POST(String(""));
  reportHttpAttempt("heartbeat", code, requestStarted, tls);
  http.end();
  Serial.printf("[Server] Check-in HTTP %d.\n", code);
}
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
